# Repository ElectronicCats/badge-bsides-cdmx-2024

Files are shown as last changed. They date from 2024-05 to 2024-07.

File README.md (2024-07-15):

# Badge bsides CDMX 2024

## Getting started

1. Connect Badge via USB to your computer.
2. Open the serial port indicated for the badge on your computer through a program such as Arduino IDE, Putty or Screen at 115200 bauds.
3. The badge text should appear in the terminal.

## Tecnologia

- ESP32C6
- Neopixel LEDs
- USB C
- Display OLED
- 2x AA Battery Holder
- Shitty Addon Connector

## Gratitude
Do you want to say thank you? Tag these companies on social networks and show them your badge, thanks to them it is possible

- [HSBC](https://www.hsbc.com.mx/)
- [ElectronicCats](https://electroniccats.com/)
- [Bsides CDMX](https://bsidescdmx.org/)

## License

Electronic Cats invests time and resources providing this open source design, please support Electronic Cats and open-source hardware by purchasing products from Electronic Cats!

Designed by Electronic Cats.

Hardware released under an CERN Open Hardware Licence v1.2. See the LICENSE_HARDWARE file for more information.

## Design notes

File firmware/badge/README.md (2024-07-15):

# BSides badge developer guide

This document is intended to help developers get started with the BSides badge firmware. The badge is based on the ESP32 microcontroller and is programmed using the ESP-IDF framework.

## Getting started

1. Install the ESP-IDF framework by following the instructions at https://docs.espressif.com/projects/esp-idf/en/latest/get-started/index.html

2. Clone the BSides badge firmware repository:

Using HTTPS:
```
git clone https://github.com/ElectronicCats/badge-bsides-cdmx-2024.git
```

Using SSH:
```
git clone git@github.com:ElectronicCats/badge-bsides-cdmx-2024.git
```

3. Change to the firmware directory:
```
cd badge-bsides-cdmx-2024/firmware/badge
```

4. Connect your badge to your computer using a USB cable and check the port it is connected to.

> On Windows, you can check it in the Device Manager, on Linux you can check it with the `ls /dev/ttyUSB*` or `ls /dev/ttyACM*` command, and on macOS you can check it with the `ls /dev/cu.usb*` command.

6. Set the target to ESP32-C6:

```bash
idf.py set-target esp32c6
```

6. Build the firmware:

```bash
idf.py build
```

7. Flash the firmware:

```bash
idf.py -p $PORT flash
```

> Replace `$PORT` with the port your badge is connected to.

8. Monitor the output:

```bash
idf.py -p $PORT monitor
```

> You can do this steps at once by running `make all`.

## Using badge_connect_src library

The project uses the [badge_connect_bin](https://github.com/ElectronicCats/badge_connect_bin) library to interact with badges from different events. It is a pre-compiled version, so you can't modify it. If you need to debug, modify or add new features, you can use the source version.

To use the source version, follow these steps:

1. Clone the badge_connect_src repository (Not inside this repository, of course):

Using HTTPS:

```bash
git clone https://github.com/ElectronicCats/badge_connect_src.git
```

Using SSH:

```bash
git clone git@github.com:ElectronicCats/badge_connect_src.git
```

2. Get the path to the badge_connect_src directory:

```bash
cd badge_connect_src/
pwd
```

3. Set the path to an environment variable:

```bash
export BADGE_CONNECT_SRC_PATH=/path/to/badge_connect_src
```

That's it! Now you are using the source version. To verify it, go to `firmware/badge` in this project and run `idf.py menuconfig`. It should show you an interface where you can modify some options, if you see `Badge Connect  --->` you are using the source version.

To go back to the binary version, just unset the environment variable:

```bash
unset BADGE_CONNECT_SRC_PATH
```

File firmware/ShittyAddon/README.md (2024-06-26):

## Characteristics

* Microcontroller Puya PY32F002A    
  * PY32F002Ax5(20KB Flash/3KB RAM) SPI, USART, I2C, ADC.

## License
<a>
  
</a>

Designed by Electronic Cats for HackGDL

Electronic Cats invests time and resources in providing this open-source design. Please support Electronic Cats and open-source hardware by purchasing products from Electronic Cats!

Hardware released under ...

# PY32F0 SDK reference for Windows

[How to install the SDK for windows](https://github.com/ElectronicCats/puya-projects)

* Puya PY32F0 seriees template project for GNU Arm Embedded Toolchain
* Supported programmers: J-Link
* Supported IDE: VSCode

# File Structure

```
├── Build                       # Build results
├── Docs                        # Datesheets and User Manuals
├── Examples
│   ├── FreeRTOS                # FreeRTOS examples
│   ├── HAL                     # HAL library examples
│   └── LL                      # LL(Low Layer) library examples
├── Libraries
│   ├── BSP                     # SysTick delay and printf for debug
│   ├── BSP_LL                  # SysTick delay and printf for debug
│   ├── CMSIS
│   ├── FreeRTOS                # FreeRTOS library
│   ├── LDScripts               # LD files
│   ├── PY32F0xx_HAL_Driver     # MCU peripheral driver
│   └── PY32F0xx_LL_Driver      # MCU low layer peripheral driver
├── Makefile                    # Make config
├── Misc
│   ├── Flash
│   │   ├── JLinkDevices        # JLink flash loaders
│   │   └── Sources             # Flash algorithm source code
│   ├── Puya.PY32F0xx_DFP.x.pack # DFP pack file for PyOCD
│   └── SVD                     # SVD files
├── README.md
├── rules.mk                    # Pre-defined rules include in Makefile 
└── User                        # User application code
```

# Requirements

* Programmer
  * J-Link: J-Link OB programmer: https://linhkienthuduc.com/jlink-ob-072-mach-nap-cho-arm-cortex-m
* SEGGER J-Link Software and Documentation pack [https://www.segger.com/downloads/jlink/](https://www.segger.com/downloads/jlink/)
* GNU Arm Embedded Toolchain
* Make 

# Try Other Examples

[Forked Repository](https://github.com/IOsetting/py32f0-template)
More examples can be found in *Examples* folder of the forked repository, copy and replace the files under *User* folder of this repository to try different examples.

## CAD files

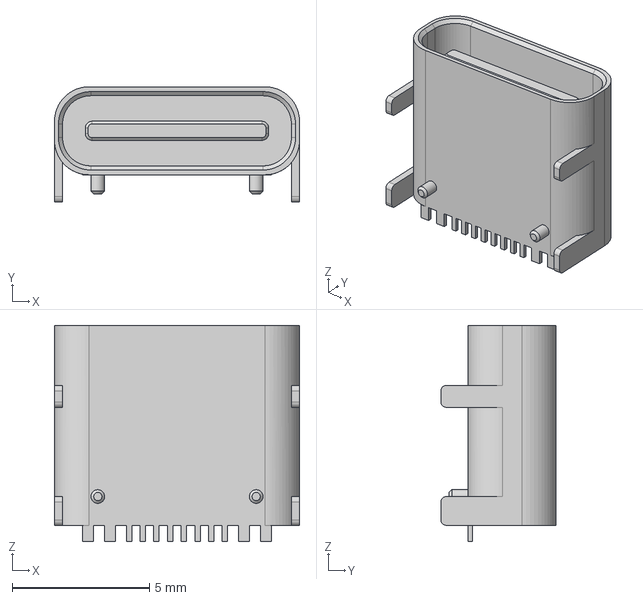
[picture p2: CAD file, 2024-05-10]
hardware/3d/HRO TYPE-C-31-M-12.step
8.94 x 4.21 x 7.90 mm

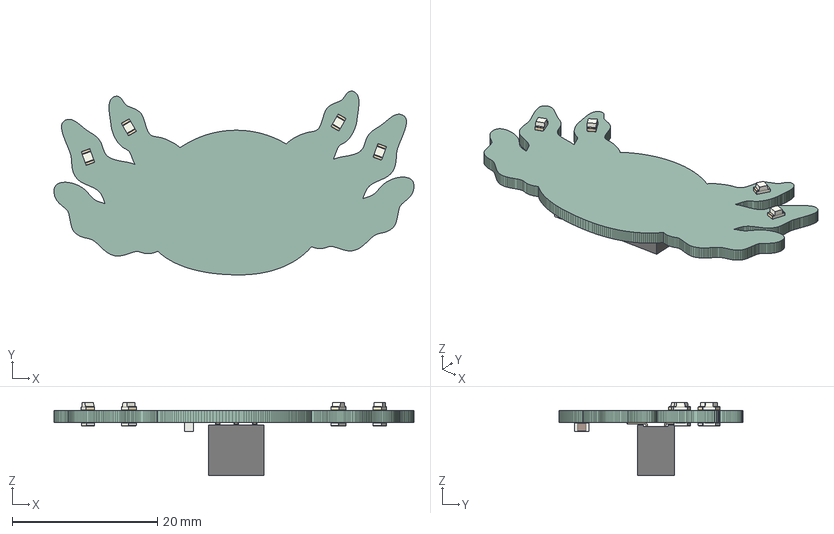
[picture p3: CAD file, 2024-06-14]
hardware/Bsides_2024_ShittyAddon/Bsides_2024_ShittyAddon.step
49.6 x 25.3 x 10.1 mm
LED_0805_2012Metric x 4
C_0805_2012Metric
PinSocket_2x03_P254mm_Vertical_SMD
R_0805_2012Metric x 4
Bsides_2024_ShittyAddon_PCB

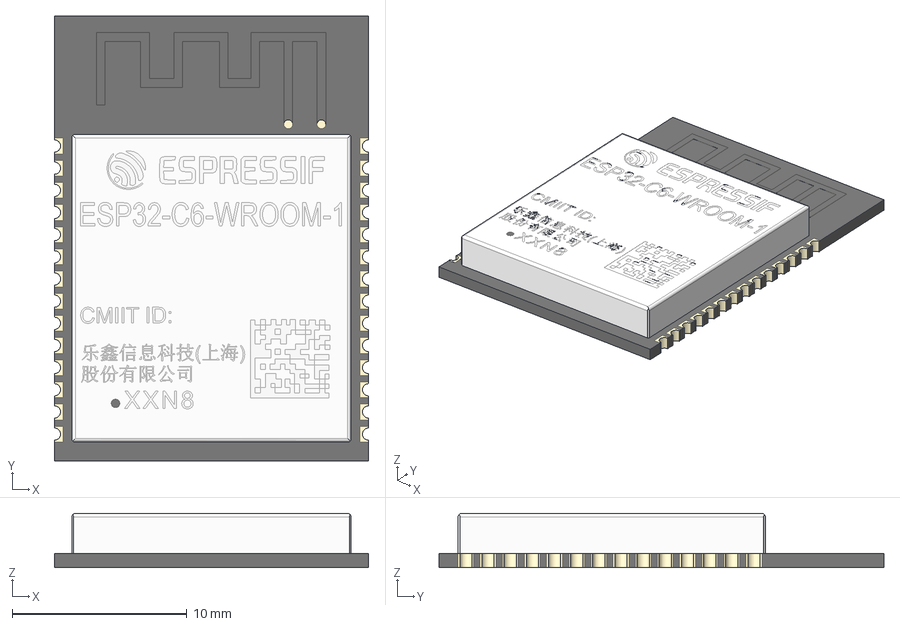
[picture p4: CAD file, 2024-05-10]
hardware/3d/ESP32-C6-WROOM-1-N4.step
18.0 x 25.5 x 3.11 mm

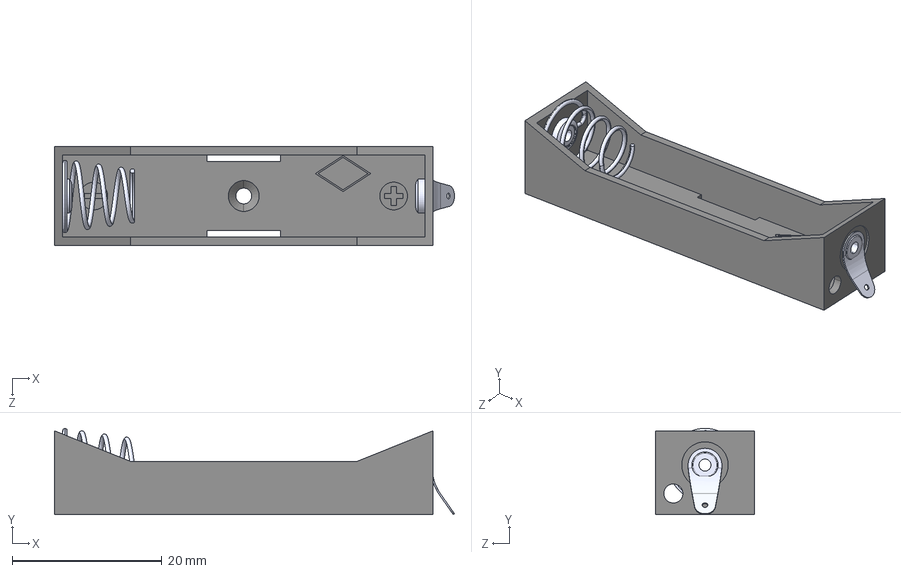
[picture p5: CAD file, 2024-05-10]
hardware/3d/BCAAAL.step
53.4 x 11.5 x 13.2 mm

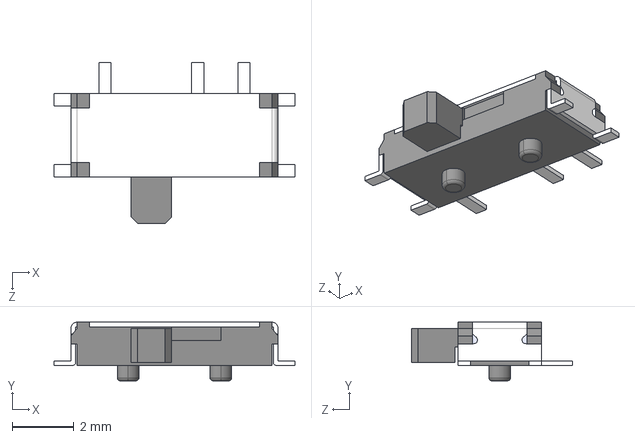
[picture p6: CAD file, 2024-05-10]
hardware/3d/MSK12C02.stp
7.80 x 1.90 x 5.20 mm

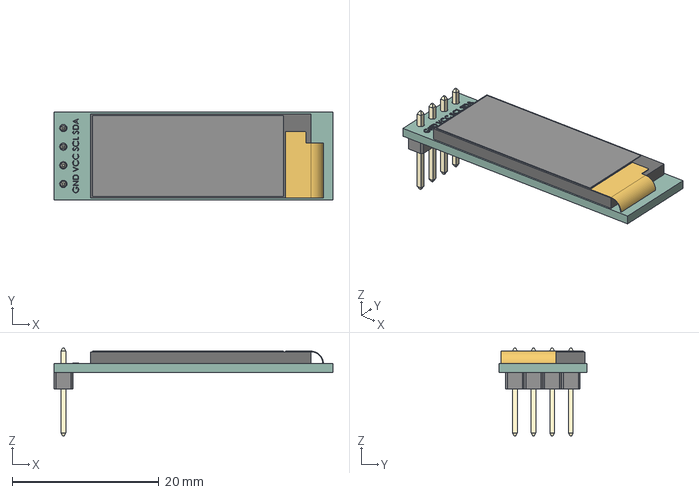
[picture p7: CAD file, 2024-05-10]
hardware/3d/128x32-OLED.STEP
38.0 x 12.0 x 11.9 mm

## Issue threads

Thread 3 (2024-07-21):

Bibliotecas Faltantes

ErikAlc-cyber, 2024-07-21:
Usando la extension de ESP-IDF apuntando a esp32c6, al intentar compilar el firmware para la badge obtengo un error de compilacion en el archivo CMAKE:

`Failed to resolve component 'esp_driver_uart'`

 El log muestra:

>  Parsed CXX implicit link information from above output:
  link line regex: [^( *|.*[/\])(riscv32-esp-elf-ld\.exe|CMAKE_LINK_STARTFILE-NOTFOUND|([^/\]+-)?ld|collect2)[^/\]*( |$)]
  ignore line: [Change Dir: C:/Users/eriks/Downloads/badge-bsides-cdmx-2024/firmware/badge/build/CMakeFiles/CMakeTmp]
  ignore line: []
  ignore line: [Run Build Command(s):C:/Users/eriks/.espressif/tools/ninja/1.11.1/ninja.exe cmTC_c5536 && [1/2] Building CXX object CMakeFiles/cmTC_c5536.dir/CMakeCXXCompilerABI.cpp.obj]
  ignore line: [Using built-in specs.]
  ignore line: [COLLECT_GCC=C:rf\.espressif\tools\riscv32-esp-elf\esp-13.2.0_20230928\riscv32-esp-elf\bin\riscv32-esp-elf-g++.exe]
  ignore line: [Target: riscv32-esp-elf]
  ignore line: [Configured with: /builds/idf/crosstool-NG/.build/HOST-x86_64-w64-mingw32/riscv32-esp-elf/src/gcc/configure --build=x86_64-build_pc-linux-gnu --host=x86_64-host_w64-mingw32 --target=riscv32-esp-elf --prefix=/builds/idf/crosstool-NG/builds/riscv32-esp-elf --exec_prefix=/builds/idf/crosstool-NG/builds/riscv32-esp-elf --with-local-prefix=/builds/idf/crosstool-NG/builds/riscv32-esp-elf/riscv32-esp-elf --with-headers=/builds/idf/crosstool-NG/builds/riscv32-esp-elf/riscv32-esp-elf/include --with-newlib --enable-threads=no --disable-shared --with-arch=rv32gc --with-abi=ilp32 --with-pkgversion='crosstool-NG esp-13.2.0_20230928' --disable-__cxa_atexit --enable-cxx-flags=-ffunction-sections --disable-libgomp --disable-libmudflap --disable-libmpx --disable-libssp --disable-libquadmath --disable-libquadmath-support --disable-libstdcxx-verbose --with-gmp=/builds/idf/crosstool-NG/.build/HOST-x86_64-w64-mingw32/riscv32-esp-elf/buildtools/complibs-host --with-mpfr=/builds/idf/crosstool-NG/.build/HOST-x86_64-w64-mingw32/riscv32-esp-elf/buildtools/complibs-host --with-mpc=/builds/idf/crosstool-NG/.build/HOST-x86_64-w64-mingw32/riscv32-esp-elf/buildtools/complibs-host --with-isl=/builds/idf/crosstool-NG/.build/HOST-x86_64-w64-mingw32/riscv32-esp-elf/buildtools/complibs-host --enable-lto --enable-target-optspace --without-long-double-128 --disable-nls --enable-multiarch --enable-languages=c,c++ --disable-libstdcxx-verbose --enable-threads=posix --enable-gcov-custom-rtio --enable-libstdcxx-time=yes --with-gnu-ld]
  ignore line: [Thread model: posix]
  ignore line: [Supported LTO compression algorithms: zlib]
  ignore line: [gcc version 13.2.0 (crosstool-NG esp-13.2.0_20230928) ]
  ignore line: [COLLECT_GCC_OPTIONS='-march=rv32imac_zicsr_zifencei' '-v' '-o' 'CMakeFiles/cmTC_c5536.dir/CMakeCXXCompilerABI.cpp.obj' '-c' '-mabi=ilp32' '-misa-spec=20191213' '-march=rv32imac_zicsr_zifencei' '-dumpdir' 'CMakeFiles/cmTC_c5536.dir/']
  ignore line: [ C:/Users/eriks/.espressif/tools/riscv32-esp-elf/esp-13.2.0_20230928/riscv32-esp-elf/bin/../libexec/gcc/riscv32-esp-elf/13.2.0/cc1plus.exe -quiet -v -imultilib rv32imac_zicsr_zifencei/ilp32 -iprefix C:/Users/eriks/.espressif/tools/riscv32-esp-elf/esp-13.2.0_20230928/riscv32-esp-elf/bin/../lib/gcc/riscv32-esp-elf/13.2.0/ C:/Users/eriks/.espressif/tools/cmake/3.24.0/share/cmake-3.24/Modules/CMakeCXXCompilerABI.cpp -quiet -dumpdir CMakeFiles/cmTC_c5536.dir/ -dumpbase CMakeCXXCompilerABI.cpp.cpp -dumpbase-ext .cpp -march=rv32imac_zicsr_zifencei -mabi=ilp32 -misa-spec=20191213 -march=rv32imac_zicsr_zifencei -version -o C:\AppData\Local\Temp\ccWxQuzr.s]
  ignore line: [GNU C++17 (crosstool-NG esp-13.2.0_20230928) version 13.2.0 (riscv32-esp-elf)]
  ignore line: [	compiled by GNU C version 6.3.0 20170516  GMP version 6.2.1  MPFR version 4.1.0  MPC version 1.2.1  isl version isl-0.24-GMP]
  ignore line: []
  ignore line: [GGC heuristics: --param ggc-min-expand=100 --param ggc-min-heapsize=131072]
  ignore line: [ignoring duplicate directory "C:/Users/eriks/.espressif/tools/riscv32-esp-elf/esp-13.2.0_20230928/riscv32-esp-elf/lib/gcc/../../lib/gcc/riscv32-esp-elf/13.2.0/../../../../riscv32-esp-elf/include/c++/13.2.0"]
  ignore line: [ignoring duplicate directory "C:/Users/eriks/.espressif/tools/riscv32-esp-elf/esp-13.2.0_20230928/riscv32-esp-elf/lib/gcc/../../lib/gcc/riscv32-esp-elf/13.2.0/../../../../riscv32-esp-elf/include/c++/13.2.0/riscv32-esp-elf/rv32imac_zicsr_zifencei/ilp32"]
  ignore line: [ignoring duplicate directory "C:/Users/eriks/.espressif/tools/riscv32-esp-elf/esp-13.2.0_20230928/riscv32-esp-elf/lib/gcc/../../lib/gcc/riscv32-esp-elf/13.2.0/../../../../riscv32-esp-elf/include/c++/13.2.0/backward"]
  ignore line: [ignoring duplicate directory "C:/Users/eriks/.espressif/tools/riscv32-esp-elf/esp-13.2.0_20230928/riscv32-esp-elf/lib/gcc/../../lib/gcc/riscv32-esp-elf/13.2.0/include"]
  ignore line: [ignoring duplicate directory "C:/Users/eriks/.espressif/tools/riscv32-esp-elf/esp-13.2.0_20230928/riscv32-esp-elf/lib/gcc/../../lib/gcc/riscv32-esp-elf/13.2.0/include-fixed"]
  ignore line: [ignoring duplicate directory "C:/Users/eriks/.espressif/tools/riscv32-esp-elf/esp-13.2.0_20230928/riscv32-esp-elf/lib/gcc/../../lib/gcc/riscv32-esp-elf/13.2.0/../../../../riscv32-esp-elf/sys-include"]
  ignore line: [ignoring duplicate directory "C:/Users/eriks/.espressif/tools/riscv32-esp-elf/esp-13.2.0_20230928/riscv32-esp-elf/lib/gcc/../../lib/gcc/riscv32-esp-elf/13.2.0/../../../../riscv32-esp-elf/include"]
  ignore line: [#include "..." search starts here:]
  ignore line: [#include <...> search starts here:]
  ignore line: [ C:/Users/eriks/.espressif/tools/riscv32-esp-elf/esp-13.2.0_20230928/riscv32-esp-elf/bin/../lib/gcc/riscv32-esp-elf/13.2.0/../../../../riscv32-esp-elf/include/c++/13.2.0]
  ignore line: [ C:/Users/eriks/.espressif/tools/riscv32-esp-elf/esp-13.2.0_20230928/riscv32-esp-elf/bin/../lib/gcc/riscv32-esp-elf/13.2.0/../../../../riscv32-esp-elf/include/c++/13.2.0/riscv32-esp-elf/rv32imac_zicsr_zifencei/ilp32]
  ignore line: [ C:/Users/eriks/.espressif/tools/riscv32-esp-elf/esp-13.2.0_20230928/riscv32-esp-elf/bin/../lib/gcc/riscv32-esp-elf/13.2.0/../../../../riscv32-esp-elf/include/c++/13.2.0/backward]
  ignore line: [ C:/Users/eriks/.espressif/tools/riscv32-esp-elf/esp-13.2.0_20230928/riscv32-esp-elf/bin/../lib/gcc/riscv32-esp-elf/13.2.0/include]
  ignore line: [ C:/Users/eriks/.espressif/tools/riscv32-esp-elf/esp-13.2.0_20230928/riscv32-esp-elf/bin/../lib/gcc/riscv32-esp-elf/13.2.0/include-fixed]
  ignore line: [ C:/Users/eriks/.espressif/tools/riscv32-esp-elf/esp-13.2.0_20230928/riscv32-esp-elf/bin/../lib/gcc/riscv32-esp-elf/13.2.0/../../../../riscv32-esp-elf/sys-include]
  ignore line: [ C:/Users/eriks/.espressif/tools/riscv32-esp-elf/esp-13.2.0_20230928/riscv32-esp-elf/bin/../lib/gcc/riscv32-esp-elf/13.2.0/../../../../riscv32-esp-elf/include]
  ignore line: [End of search list.]
  ignore line: [Compiler executable checksum: c3899898cbd00b593a05a0e9a2f92cb0]
  ignore line: [COLLECT_GCC_OPTIONS='-march=rv32imac_zicsr_zifencei' '-v' '-o' 'CMakeFiles/cmTC_c5536.dir/CMakeCXXCompilerABI.cpp.obj' '-c' '-mabi=ilp32' '-misa-spec=20191213' '-march=rv32imac_zicsr_zifencei' '-dumpdir' 'CMakeFiles/cmTC_c5536.dir/']
  ignore line: [ C:/.espressif/tools/riscv32-esp-elf/esp-13.2.0_20230928/riscv32-esp-elf/bin/../lib/gcc/riscv32-esp-elf/13.2.0/../../../../riscv32-esp-elf/bin/as.exe -v --traditional-format -march=rv32imac_zicsr_zifencei -march=rv32imac_zicsr_zifencei -mabi=ilp32 -misa-spec=20191213 -o CMakeFiles/cmTC_c5536.dir/CMakeCXXCompilerABI.cpp.obj C:\AppData\Local\Temp\ccWxQuzr.s]
  ignore line: [GNU assembler version 2.41 (riscv32-esp-elf) using BFD version (crosstool-NG esp-13.2.0_20230928) 2.41]
  ignore line: [COMPILER_PATH=C:/.espressif/tools/riscv32-esp-elf/esp-13.2.0_20230928/riscv32-esp-elf/bin/../libexec/gcc/riscv32-esp-elf/13.2.0/]
  ignore line: [C:/.espressif/tools/riscv32-esp-elf/esp-13.2.0_20230928/riscv32-esp-elf/bin/../libexec/gcc/]
  ignore line: [C:/.espressif/tools/riscv32-esp-elf/esp-13.2.0_20230928/riscv32-esp-elf/bin/../lib/gcc/riscv32-esp-elf/13.2.0/../../../../riscv32-esp-elf/bin/]
  ignore line: [LIBRARY_PATH=C:/.espressif/tools/riscv32-esp-elf/esp-13.2.0_20230928/riscv32-esp-elf/bin/../lib/gcc/riscv32-esp-elf/13.2.0/rv32imac_zicsr_zifencei/ilp32/]
  ignore line: [C:/.espressif/tools/riscv32-esp-elf/esp-13.2.0_20230928/riscv32-esp-elf/bin/../lib/gcc/riscv32-esp-elf/13.2.0/../../../../riscv32-esp-elf/lib/rv32imac_zicsr_zifencei/ilp32/]
  ignore line: [C:/.espressif/tools/riscv32-esp-elf/esp-13.2.0_20230928/riscv32-esp-elf/bin/../lib/gcc/riscv32-esp-elf/13.2.0/]
  ignore line: [C:/.espressif/tools/riscv32-esp-elf/esp-13.2.0_20230928/riscv32-esp-elf/bin/../lib/gcc/]
  ignore line: [C:/.espressif/tools/riscv32-esp-elf/esp-13.2.0_20230928/riscv32-esp-elf/bin/../lib/gcc/riscv32-esp-elf/13.2.0/../../../../riscv32-esp-elf/lib/]
  ignore line: [COLLECT_GCC_OPTIONS='-march=rv32imac_zicsr_zifencei' '-v' '-o' 'CMakeFiles/cmTC_c5536.dir/CMakeCXXCompilerABI.cpp.obj' '-c' '-mabi=ilp32' '-misa-spec=20191213' '-march=rv32imac_zicsr_zifencei' '-dumpdir' 'CMakeFiles/cmTC_c5536.dir/CMakeCXXCompilerABI.cpp.']
  ignore line: [[2/2] Linking CXX executable cmTC_c5536]
  ignore line: [Using built-in specs.]
  ignore line: [Reading specs from C:/.espressif/tools/riscv32-esp-elf/esp-13.2.0_20230928/riscv32-esp-elf/bin/../lib/gcc/riscv32-esp-elf/13.2.0/../../../../riscv32-esp-elf/lib/nosys.specs]
  ignore line: [rename spec link_gcc_c_sequence to nosys_link_gcc_c_sequence]
  ignore line: [COLLECT_GCC=C:\.espressif\tools\riscv32-esp-elf\esp-13.2.0_20230928\riscv32-esp-elf\bin\riscv32-esp-elf-g++.exe]
  ignore line: [COLLECT_LTO_WRAPPER=C:/.espressif/tools/riscv32-esp-elf/esp-13.2.0_20230928/riscv32-esp-elf/bin/../libexec/gcc/riscv32-esp-elf/13.2.0/lto-wrapper.exe]
  ignore line: [Target: riscv32-esp-elf]
  ignore line: [Configured with: /builds/idf/crosstool-NG/.build/HOST-x86_64-w64-mingw32/riscv32-esp-elf/src/gcc/configure --build=x86_64-build_pc-linux-gnu --host=x86_64-host_w64-mingw32 --target=riscv32-esp-elf --prefix=/builds/idf/crosstool-NG/builds/riscv32-esp-elf --exec_prefix=/builds/idf/crosstool-NG/builds/riscv32-esp-elf --with-local-prefix=/builds/idf/crosstool-NG/builds/riscv32-esp-elf/riscv32-esp-elf --with-headers=/builds/idf/crosstool-NG/builds/riscv32-esp-elf/riscv32-esp-elf/include --with-newlib --enable-threads=no --disable-shared --with-arch=rv32gc --with-abi=ilp32 --with-pkgversion='crosstool-NG esp-13.2.0_20230928' --disable-__cxa_atexit --enable-cxx-flags=-ffunction-sections --disable-libgomp --disable-libmudflap --disable-libmpx --disable-libssp --disable-libquadmath --disable-libquadmath-support --disable-libstdcxx-verbose --with-gmp=/builds/idf/crosstool-NG/.build/HOST-x86_64-w64-mingw32/riscv32-esp-elf/buildtools/complibs-host --with-mpfr=/builds/idf/crosstool-NG/.build/HOST-x86_64-w64-mingw32/riscv32-esp-elf/buildtools/complibs-host --with-mpc=/builds/idf/crosstool-NG/.build/HOST-x86_64-w64-mingw32/riscv32-esp-elf/buildtools/complibs-host --with-isl=/builds/idf/crosstool-NG/.build/HOST-x86_64-w64-mingw32/riscv32-esp-elf/buildtools/complibs-host --enable-lto --enable-target-optspace --without-long-double-128 --disable-nls --enable-multiarch --enable-languages=c,c++ --disable-libstdcxx-verbose --enable-threads=posix --enable-gcov-custom-rtio --enable-libstdcxx-time=yes --with-gnu-ld]
  ignore line: [Thread model: posix]
  ignore line: [Supported LTO compression algorithms: zlib]
  ignore line: [gcc version 13.2.0 (crosstool-NG esp-13.2.0_20230928) ]
  ignore line: [COMPILER_PATH=C:/.espressif/tools/riscv32-esp-elf/esp-13.2.0_20230928/riscv32-esp-elf/bin/../libexec/gcc/riscv32-esp-elf/13.2.0/]
  ignore line: [C:/.espressif/tools/riscv32-esp-elf/esp-13.2.0_20230928/riscv32-esp-elf/bin/../libexec/gcc/]
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
ErikAlc-cyber, 2024-07-22:
Ya encontre una solucion, se debe usar especificamente ESP-IDF v5.3.0 para que incluya las bibliotecas necesarias

Closed 2024-07-22.

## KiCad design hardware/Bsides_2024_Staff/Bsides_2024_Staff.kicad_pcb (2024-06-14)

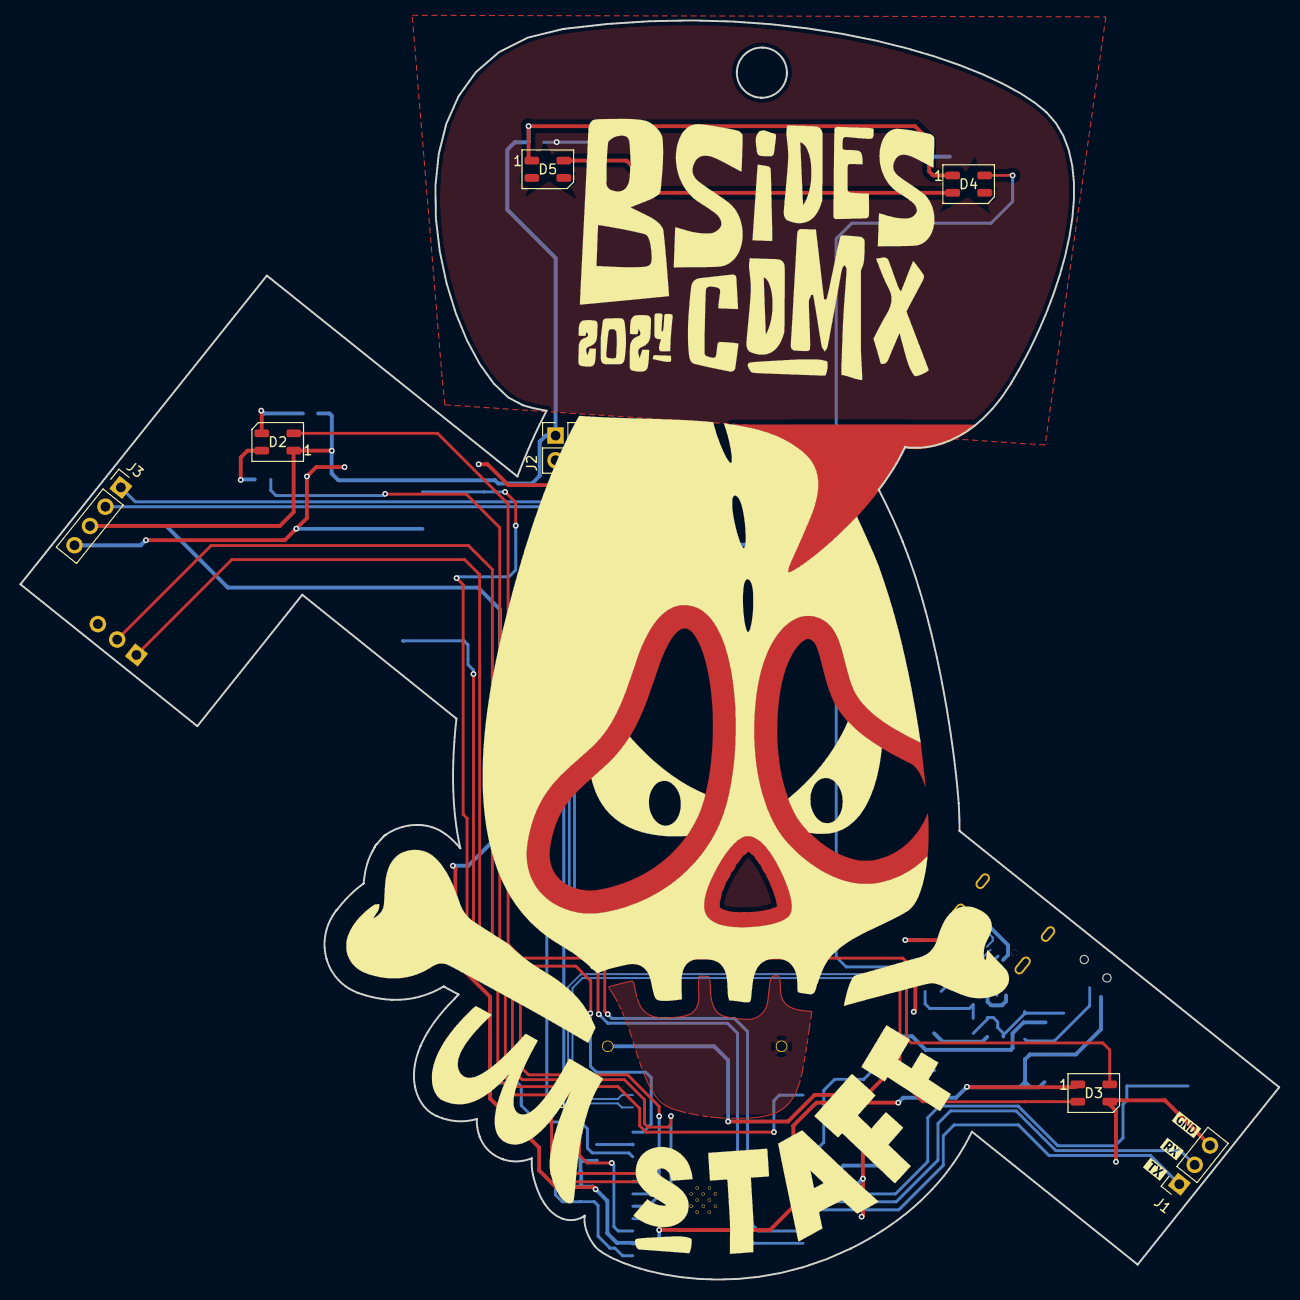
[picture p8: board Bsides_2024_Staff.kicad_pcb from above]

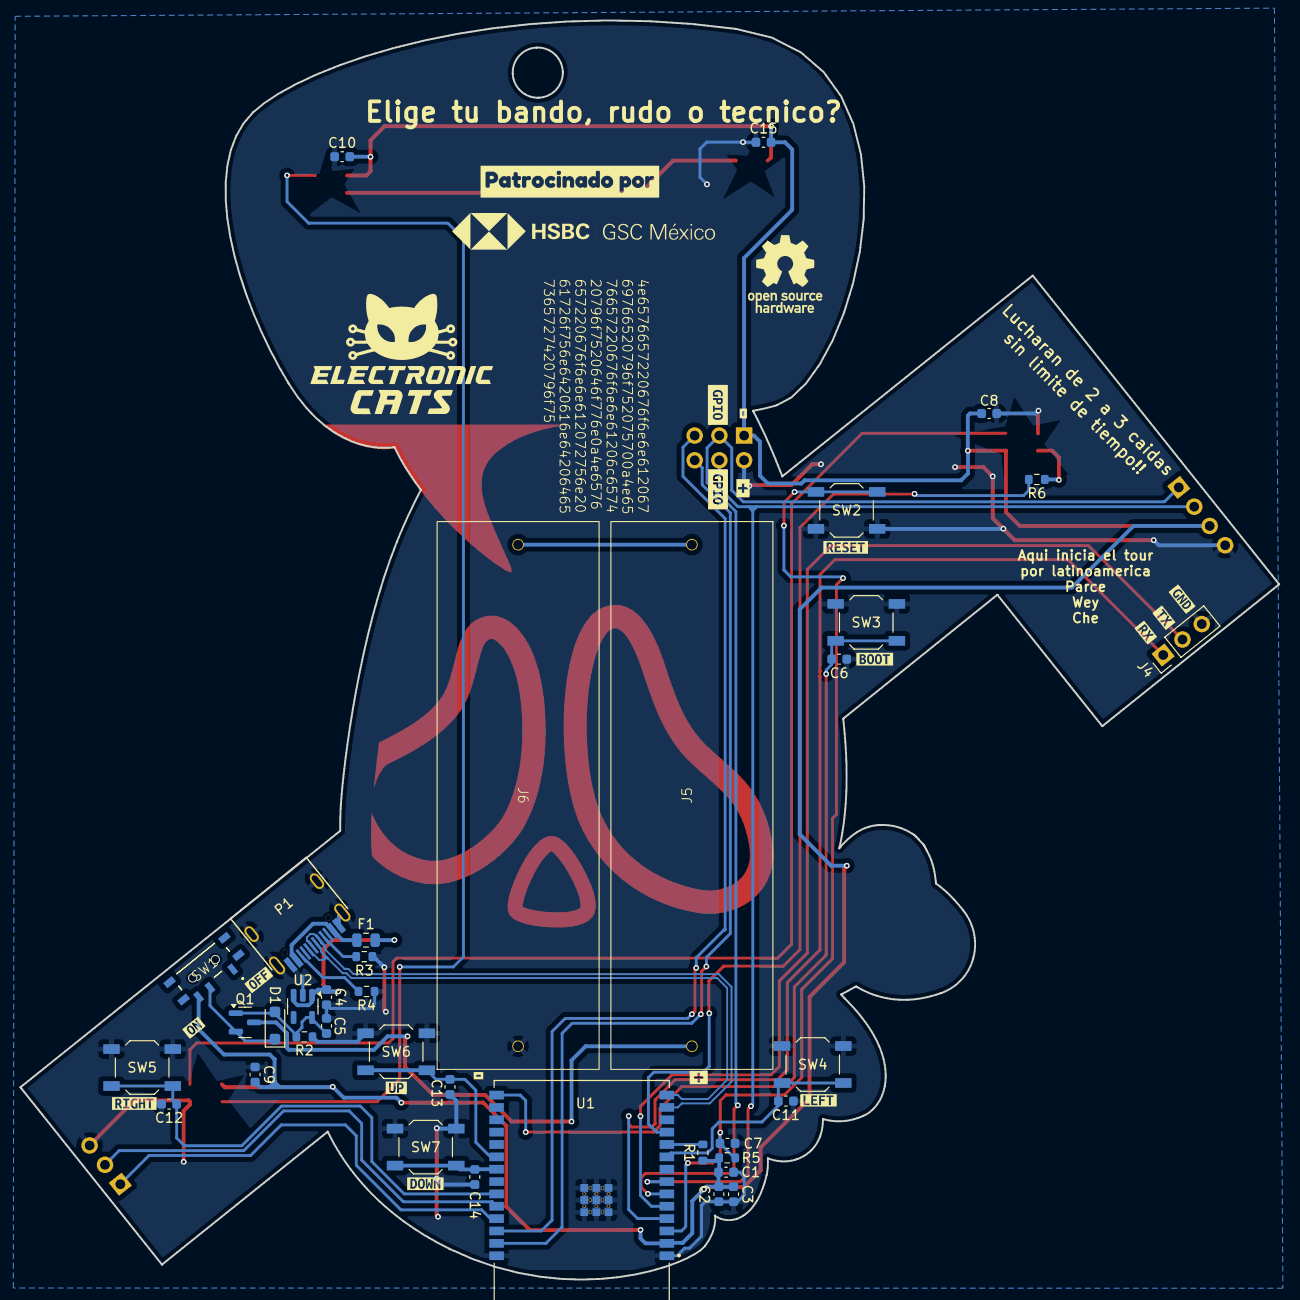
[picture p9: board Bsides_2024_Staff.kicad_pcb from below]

Board: 2 copper layers, 129.4 x 129.4 mm, 66 parts (55 on the bottom side), 32 nets.

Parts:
C1: 1uF; C_0603_1608Metric
C2, C3, C4, C5: 10uF; C_0603_1608Metric
C6, C7, C8, C9, C10, C11, C12, C13, C14, C15: 0.1uF; C_0603_1608Metric
D1: MBR120; D_SOD-123F
D2, D3, D4, D5: WS2812B; LED_WS2812B-Mini_PLCC4_3.5x3.5mm
F1: 0.75A; Fuse_0805_2012Metric
J1: Serial_IN; PinSocket_1x03_P2.54mm_Vertical
J2: Add_On; PinSocket_2x03_P2.54mm_Vertical
J3: OLED; Display OLED 128 x32
J4: Serial_OUT; PinHeader_1x03_P2.54mm_Vertical
J5, J6: Battery; BH-AA-A1AJ020
P1: USB_C_Plug_USB2.0; C393939
Q1: DMG3415U-7; SOT-23
R1: 3.3K; R_0603_1608Metric
R2: 100K; R_0603_1608Metric
R3, R4: 5k1; R_0603_1608Metric
R5: 10K; R_0603_1608Metric
R6: 470; R_0603_1608Metric
Ref**: Val**; Badge_Staff_Bsides_2024_CDMX
SW1: ON; MSK12C02
SW2, SW4, SW6: RESET; SW_SPST_TL3342
SW3: BOOT; SW_SPST_TL3342
SW5, SW7: SW_SPST_TL3342
U1: ESP32-C6-WROOM-1-N4; XCVR_ESP32-C6-WROOM-1-N8
U2: AP2112K-3.3; SOT-23-5
kibuzzard-666B5A62, kibuzzard-666B5A62#2: G***; kibuzzard-666B5A62
kibuzzard-666B5A91, kibuzzard-666B5A91#2: G***; kibuzzard-666B5A91
kibuzzard-666B5AA1, kibuzzard-666B5AA1#2: G***; kibuzzard-666B5AA1
kibuzzard-666B5BCA, kibuzzard-666B5BCA#2: G***; kibuzzard-666B5BCA
kibuzzard-666B5C0A, kibuzzard-666B5C0A#2: G***; kibuzzard-666B5C0A
kibuzzard-666C8E87: G***; kibuzzard-666C8E87
kibuzzard-666C76B6: G***; kibuzzard-666C76B6
kibuzzard-666C89E6: G***; kibuzzard-666C89E6
kibuzzard-666C89FF: G***; kibuzzard-666C89FF
kibuzzard-666C926F: G***; kibuzzard-666C926F
kibuzzard-666C7661: G***; kibuzzard-666C7661
kibuzzard-666C8913: G***; kibuzzard-666C8913
kibuzzard-666C8921: G***; kibuzzard-666C8921
kibuzzard-666C8949: G***; kibuzzard-666C8949
kibuzzard-666C8959: G***; kibuzzard-666C8959
kibuzzard-666C9266: G***; kibuzzard-666C9266

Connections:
+BATT: J5.2, Q1.3 (D)
/BOOT: C6.2, SW3.2, U1.15 (IO9)
/D+: P1.A6 (D+), U1.14 (IO13)
/D-: P1.A7 (D-), U1.13 (IO12)
/DOWN: C14.2, SW7.2, U1.21 (IO23)
/EN: C7.2, R5.1, SW2.2, U1.3 (EN)
/GPIO2: J2.6, U1.27 (IO2)
/GPIO3: J2.5, U1.26 (IO3)
/LEFT: C11.2, SW4.2, U1.9 (IO1)
/PIN: R6.1, U1.11 (IO10)
/RIGHT: C12.2, SW5.2, U1.23 (IO15)
/RX: J1.2, U1.24 (RXD0)
/RX1: J4.1, U1.4 (IO4)
/SCL: J2.4, J3.2, U1.7 (IO7)
/SDA: J2.3, J3.1, U1.6 (IO6)
/TX: J1.1, U1.25 (TXD0)
/TX1: J4.2, U1.5 (IO5)
/UP: C13.2, SW6.2, U1.20 (IO22)
/VOUT: C1.1, C2.1, C3.1, C8.2, C9.2, C10.2, C15.2, D2.1 (VDD), D3.1 (VDD), D4.1 (VDD), D5.1 (VDD), J2.1, J3.3, R1.2, R5.2, SW1.3 (A), U1.2 (3V3)
GND: C1.2, C2.2, C3.2, C4.2, C5.2, C6.1, C7.1, C8.1, C9.1, C10.1, C11.1, C12.1, C13.1, C14.1, C15.1, D2.3 (VSS), D3.3 (VSS), D4.3 (VSS), D5.3 (VSS), J1.3, J2.2, J3.4, J4.3, J6.1, P1.A1 (GND), P1.S1 (SHIELD), R2.2, R3.1, R4.1, SW2.1, SW3.1, SW4.1, SW5.1, SW6.1, SW7.1, U1.1 (GND), U1.28 (GND), U1.29 (GND), U1.30 (GND), U1.31 (GND), U1.32 (GND), U1.33 (GND), U1.34 (GND), U1.35 (GND), U1.36 (GND), U1.37 (GND), U2.2 (GND)
unnamed: C5.1, D1.2 (A), Q1.1 (G), R2.1, U2.5 (VOUT)
unnamed: D1.1 (K), Q1.2 (S), SW1.2 (B)
unnamed: D2.4 (DIN), R6.2
unnamed: D2.2 (DOUT), D3.4 (DIN)
unnamed: D3.2 (DOUT), D4.4 (DIN)
unnamed: D4.2 (DOUT), D5.4 (DIN)
unnamed: F1.1, P1.A4 (VBUS)
unnamed: J5.1, J6.2
unnamed: P1.A5 (CC), R3.2
unnamed: P1.B5 (VCONN), R4.2
unnamed: R1.1, U1.10 (IO8)
VBUS: C4.1, F1.2, U2.1 (VIN), U2.3 (EN)

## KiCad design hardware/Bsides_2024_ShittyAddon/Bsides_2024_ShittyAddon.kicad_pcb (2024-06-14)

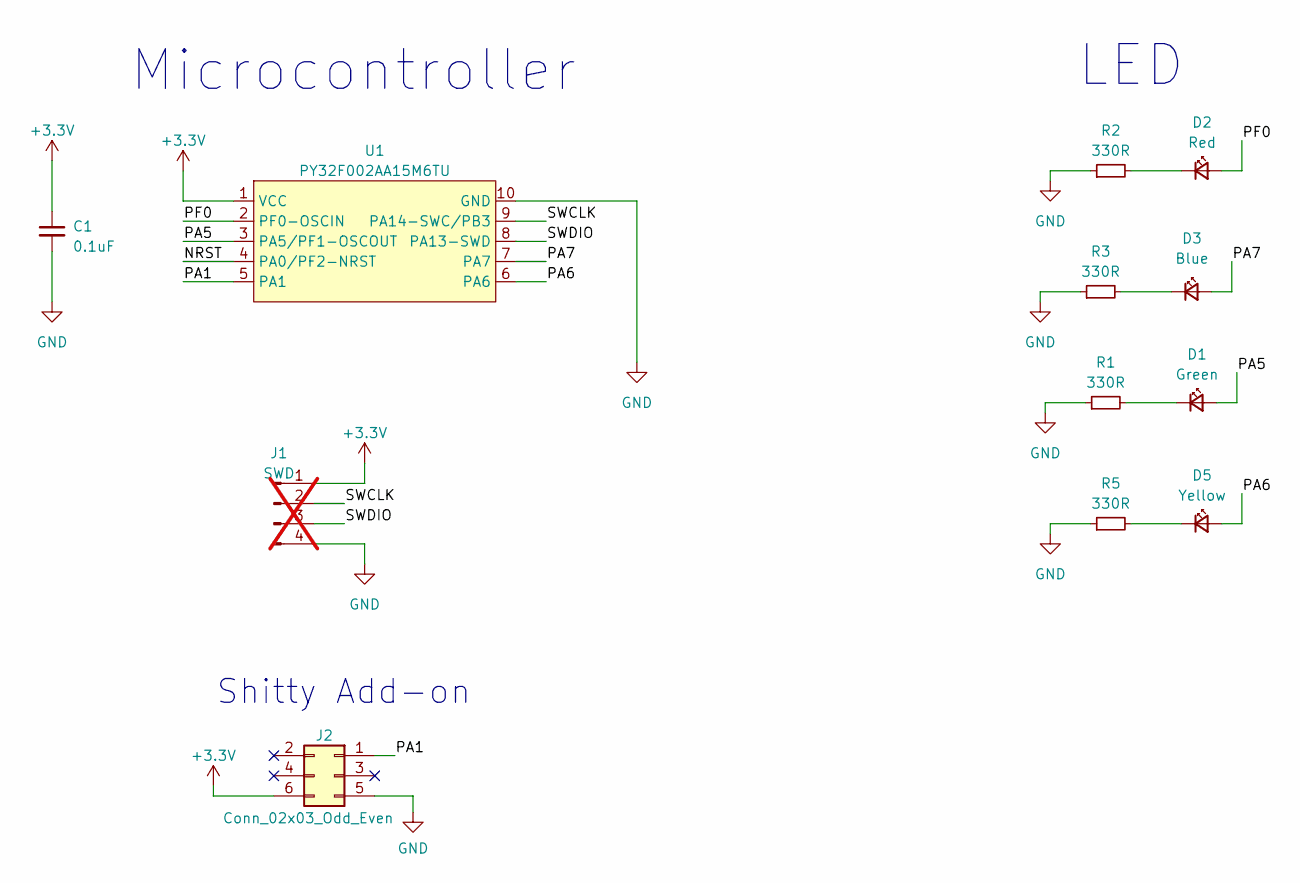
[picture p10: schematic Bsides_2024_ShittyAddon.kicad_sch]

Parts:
C1: 0.1uF; C_0805_2012Metric; LCSC# C282732
D1: Green; LED_0805_2012Metric; LCSC# C965815
D2: Red; LED_0805_2012Metric; LCSC# C965812
D3: Blue; LED_0805_2012Metric; LCSC# C205441
D5: Yellow; LED_0805_2012Metric; LCSC# C84261
J1: SWD; PinHeader_1x04_P2.54mm_Vertical; not fitted
J2: Conn_02x03_Odd_Even; B-2100N06P-B111_CKM; LCSC# C124390
R1, R2, R3, R5: 330R; R_0805_2012Metric; LCSC# C2907321
U1: PY32F002AA15M6TU; PY32F002AA15M; LCSC# C5292058

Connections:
+3.3V: C1.1, J1.1, J2.6, U1.1 (VCC)
/NRST: U1.4 (PA0/PF2-NRST)
/PA1: J2.1, U1.5 (PA1)
/PA5: D1.2 (A), U1.3 (PA5/PF1-OSCOUT)
/PA6: D5.2 (A), U1.6 (PA6)
/PA7: D3.2 (A), U1.7 (PA7)
/PF0: D2.2 (A), U1.2 (PF0-OSCIN)
/SWCLK: J1.2, U1.9 (PA14-SWC/PB3)
/SWDIO: J1.3, U1.8 (PA13-SWD)
GND: C1.2, J1.4, J2.5, R1.1, R2.1, R3.1, R5.1, U1.10 (GND)
unnamed: D1.1 (K), R1.2
unnamed: D2.1 (K), R2.2
unnamed: D3.1 (K), R3.2
unnamed: D5.1 (K), R5.2

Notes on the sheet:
Microcontroller
Shitty Add-on
LED

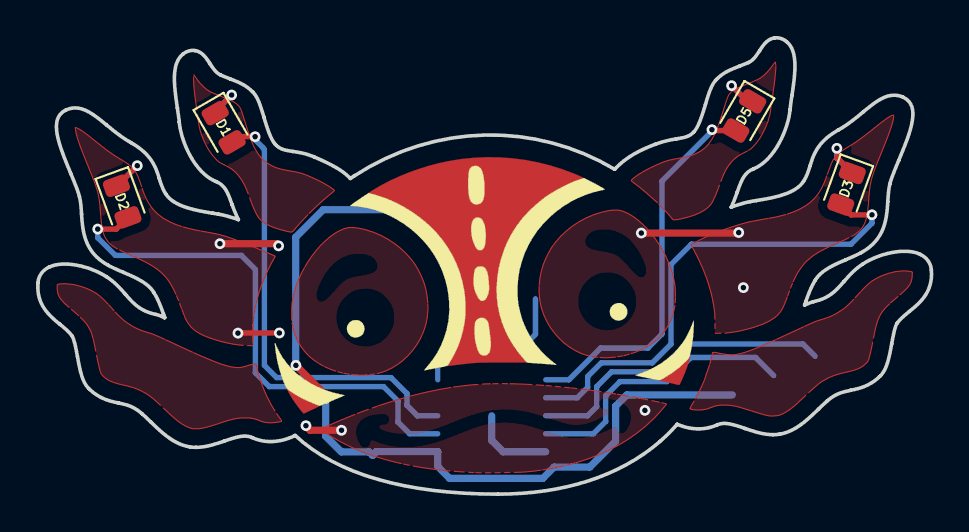
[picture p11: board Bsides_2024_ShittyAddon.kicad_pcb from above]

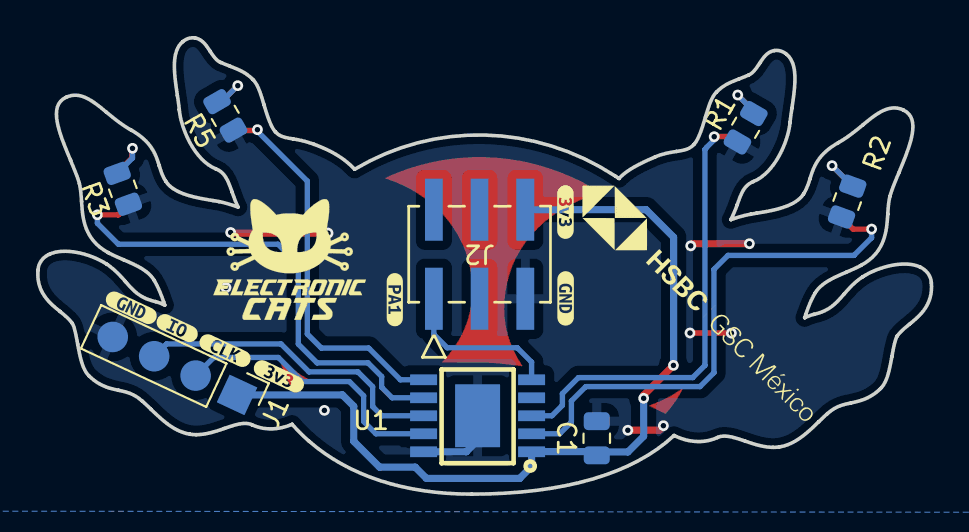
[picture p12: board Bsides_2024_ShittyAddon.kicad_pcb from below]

Board: 2 copper layers, 49.7 x 25.4 mm, 20 parts (15 on the bottom side), 13 nets.

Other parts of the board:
Ref**: Val**; Ajolote-bsidescdmx_A
kibuzzard-666C77E0, kibuzzard-666C77E0#2: G***; kibuzzard-666C77E0
kibuzzard-666C787C: G***; kibuzzard-666C787C
kibuzzard-666C7809, kibuzzard-666C7809#2: G***; kibuzzard-666C7809
kibuzzard-666C7823: G***; kibuzzard-666C7823
kibuzzard-666C7874: G***; kibuzzard-666C7874

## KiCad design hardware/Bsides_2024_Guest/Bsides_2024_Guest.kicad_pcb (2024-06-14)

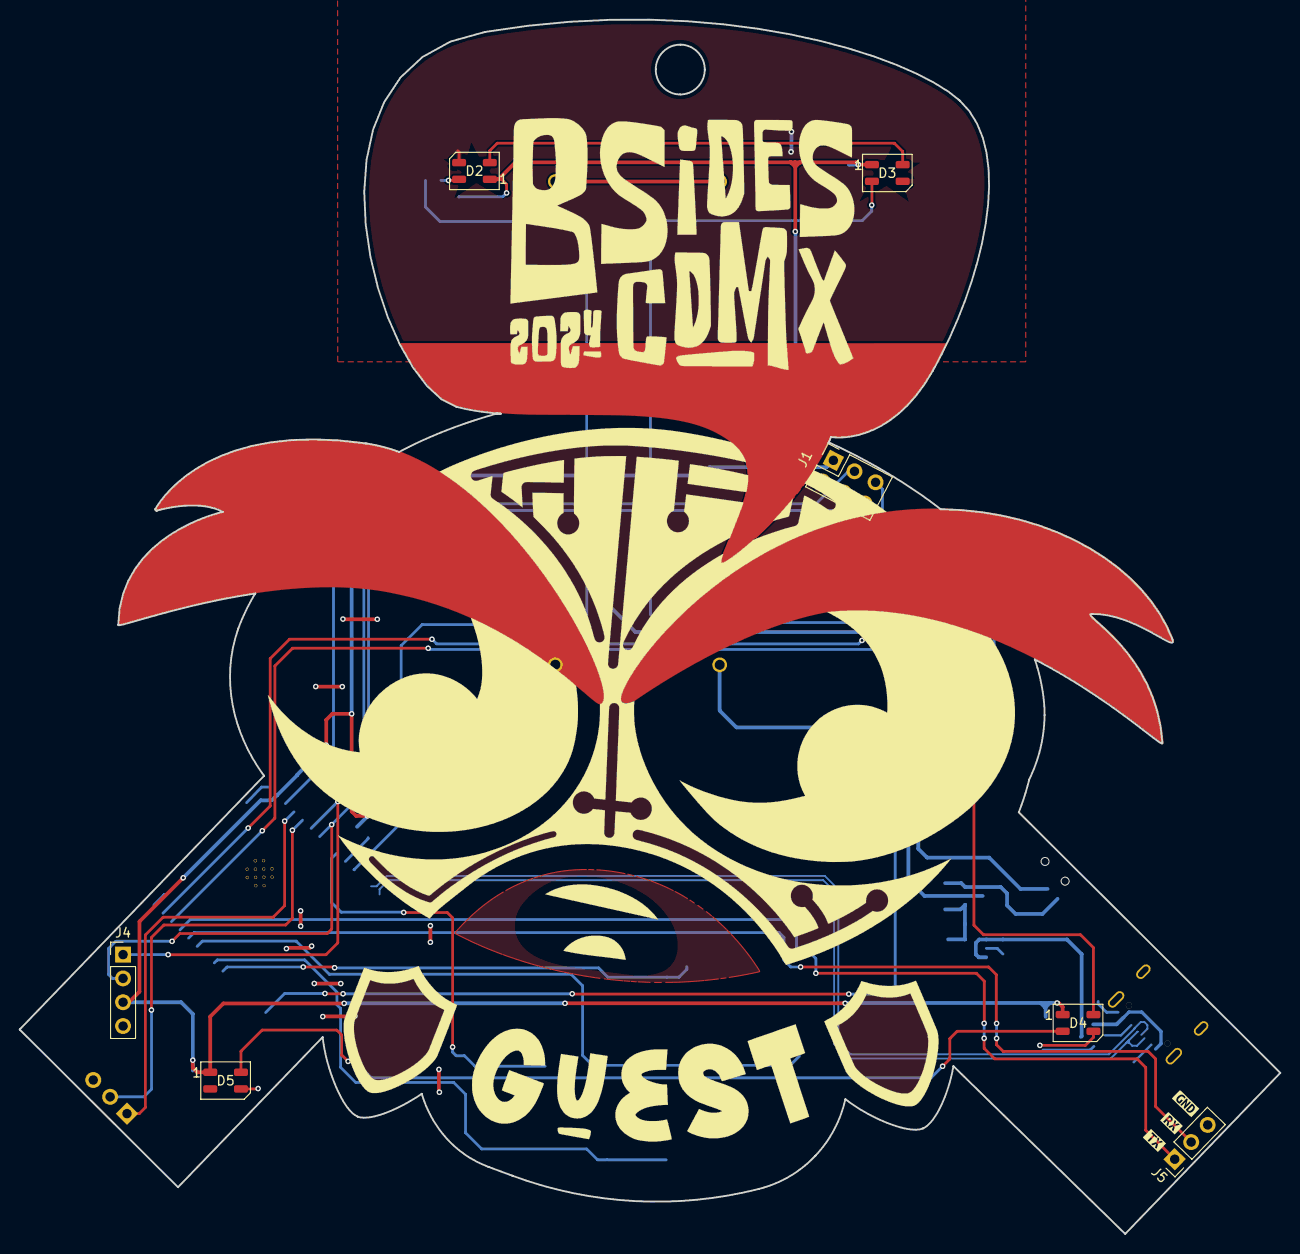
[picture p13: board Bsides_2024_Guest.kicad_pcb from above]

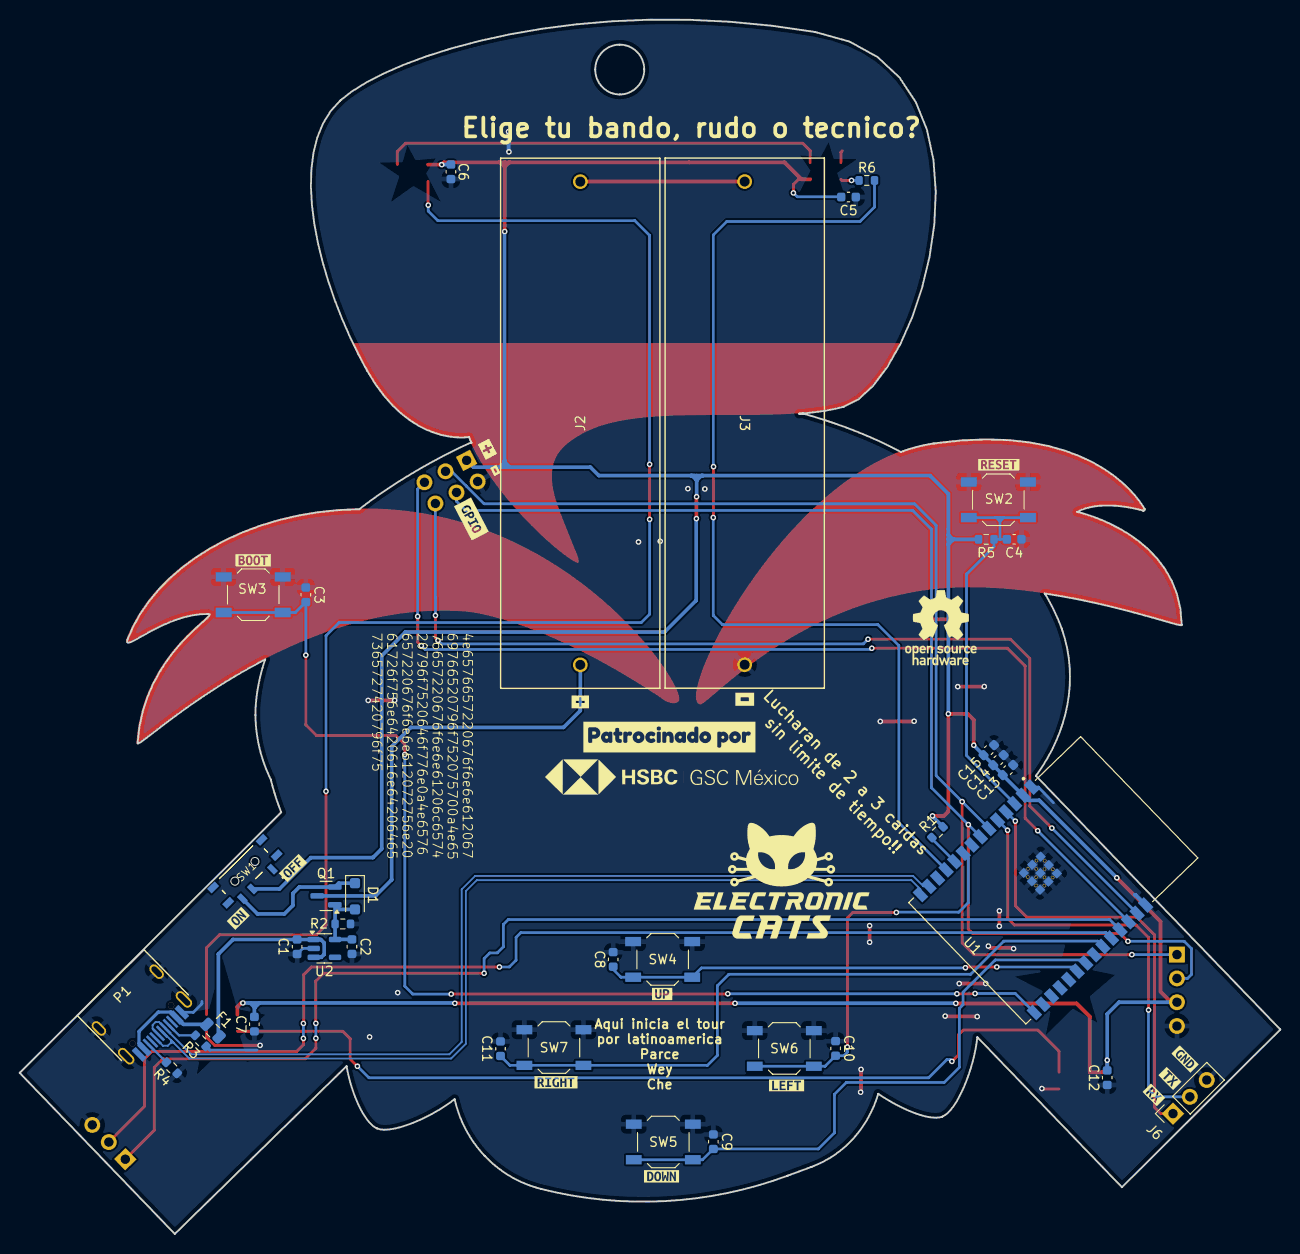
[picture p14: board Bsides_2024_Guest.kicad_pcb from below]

Board: 2 copper layers, 134.5 x 129.5 mm, 65 parts (54 on the bottom side), 32 nets.

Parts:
C1, C2, C14, C15: 10uF; C_0603_1608Metric
C3, C4, C5, C6, C7, C8, C9, C10, C11, C12: 0.1uF; C_0603_1608Metric
C13: 1uF; C_0603_1608Metric
D1: MBR120; D_SOD-123F
D2, D3, D4, D5: WS2812B; LED_WS2812B-Mini_PLCC4_3.5x3.5mm
F1: 0.75A; Fuse_0805_2012Metric
J1: Add_On; PinSocket_2x03_P2.54mm_Vertical
J2, J3: Battery; BATT_8BH-AA-A1AJ020_MYG
J4: OLED; Display OLED 128 x32
J5: Serial_IN; PinHeader_1x03_P2.54mm_Vertical
J6: Serial_OUT; PinSocket_1x03_P2.54mm_Vertical
P1: USB_C_Plug_USB2.0; C393939
Q1: DMG3415U-7; SOT-23
R1: 3.3K; R_0603_1608Metric
R2: 100K; R_0603_1608Metric
R3, R4: 5k1; R_0603_1608Metric
R5: 10K; R_0603_1608Metric
R6: 470; R_0603_1608Metric
Ref**: Val**; Badge_Guest_Bsides_2024_CDMX (1)
SW1: ON; MSK12C02
SW2, SW3, SW4, SW5, SW6, SW7: SW_SPST_TL3342
U1: ESP32-C6-WROOM-1U-N4; XCVR_ESP32-C6-WROOM-1-N8
U2: AP2112K-3.3; SOT-23-5
kibuzzard-666B5A62, kibuzzard-666B5A62#2: G***; kibuzzard-666B5A62
kibuzzard-666B5A91, kibuzzard-666B5A91#2: G***; kibuzzard-666B5A91
kibuzzard-666B5AA1, kibuzzard-666B5AA1#2: G***; kibuzzard-666B5AA1
kibuzzard-666B5BCA, kibuzzard-666B5BCA#2: G***; kibuzzard-666B5BCA
kibuzzard-666B5C0A: G***; kibuzzard-666B5C0A
kibuzzard-666B5E3B: G***; kibuzzard-666B5E3B
kibuzzard-666B5E08: G***; kibuzzard-666B5E08
kibuzzard-666B5E64: G***; kibuzzard-666B5E64
kibuzzard-666B5E88: G***; kibuzzard-666B5E88
kibuzzard-666B5E96: G***; kibuzzard-666B5E96
kibuzzard-666B5EA2: G***; kibuzzard-666B5EA2
kibuzzard-666B5ECE: G***; kibuzzard-666B5ECE
kibuzzard-666C8E87: G***; kibuzzard-666C8E87
kibuzzard-666C94C8: G***; kibuzzard-666C94C8
kibuzzard-666C662F: G***; kibuzzard-666C662F
kibuzzard-666C947A: G***; kibuzzard-666C947A

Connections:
+BATT: J2.2, Q1.3 (D)
/BOOT: C3.2, SW3.2, U1.15 (IO9)
/D+: P1.A6 (D+), U1.14 (IO13)
/D-: P1.A7 (D-), U1.13 (IO12)
/DOWN: C9.2, SW5.2, U1.21 (IO23)
/EN: C4.2, R5.1, SW2.2, U1.3 (EN)
/GPIO2: J1.6, U1.27 (IO2)
/GPIO3: J1.5, U1.26 (IO3)
/LEFT: C10.2, SW6.2, U1.9 (IO1)
/PIN: R6.1, U1.11 (IO10)
/RIGHT: C11.2, SW7.2, U1.23 (IO15)
/RX: J5.2, U1.24 (RXD0)
/RX1: J6.1, U1.4 (IO4)
/SCL: J1.4, J4.2, U1.7 (IO7)
/SDA: J1.3, J4.1, U1.6 (IO6)
/TX: J5.1, U1.25 (TXD0)
/TX1: J6.2, U1.5 (IO5)
/UP: C8.2, SW4.2, U1.20 (IO22)
/VOUT: C5.2, C6.2, C7.2, C12.2, C13.1, C14.1, C15.1, D2.1 (VDD), D3.1 (VDD), D4.1 (VDD), D5.1 (VDD), J1.1, J4.3, R1.2, R5.2, SW1.2 (B), U1.2 (3V3)
GND: C1.2, C2.2, C3.1, C4.1, C5.1, C6.1, C7.1, C8.1, C9.1, C10.1, C11.1, C12.1, C13.2, C14.2, C15.2, D2.3 (VSS), D3.3 (VSS), D4.3 (VSS), D5.3 (VSS), J1.2, J3.1, J4.4, J5.3, J6.3, P1.A1 (GND), P1.S1 (SHIELD), R2.2, R3.1, R4.1, SW2.1, SW3.1, SW4.1, SW5.1, SW6.1, SW7.1, U1.1 (GND), U1.28 (GND), U1.29 (GND), U1.30 (GND), U1.31 (GND), U1.32 (GND), U1.33 (GND), U1.34 (GND), U1.35 (GND), U1.36 (GND), U1.37 (GND), U2.2 (GND)
unnamed: C2.1, D1.2 (A), Q1.1 (G), R2.1, U2.5 (VOUT)
unnamed: D1.1 (K), Q1.2 (S), SW1.3 (A)
unnamed: D2.4 (DIN), R6.2
unnamed: D2.2 (DOUT), D3.4 (DIN)
unnamed: D3.2 (DOUT), D4.4 (DIN)
unnamed: D4.2 (DOUT), D5.4 (DIN)
unnamed: F1.1, P1.A4 (VBUS)
unnamed: J2.1, J3.2
unnamed: P1.A5 (CC), R3.2
unnamed: P1.B5 (VCONN), R4.2
unnamed: R1.1, U1.10 (IO8)
VBUS: C1.1, F1.2, U2.1 (VIN), U2.3 (EN)

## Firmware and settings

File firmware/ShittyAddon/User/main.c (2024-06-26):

/**
 ******************************************************************************
 * @file    main.c
 * @author  MCU Application Team
 * @brief   Main program body
 ******************************************************************************
 * @attention
 *
 * <h2><center>&copy; Copyright (c) Puya Semiconductor Co.
 * All rights reserved.</center></h2>
 *
 * <h2><center>&copy; Copyright (c) 2016 STMicroelectronics.
 * All rights reserved.</center></h2>
 *
 * This software component is licensed by ST under BSD 3-Clause license,
 * the "License"; You may not use this file except in compliance with the
 * License. You may obtain a copy of the License at:
 *                        opensource.org/licenses/BSD-3-Clause
 *
 * J-Link Connections: https://private-user-images.githubusercontent.com/44976441/277049150-2c44cddc-163c-4924-840f-2b99760bbca3.png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
 * PUYA instructions: https://github.com/ElectronicCats/puya-projects
 *
 ******************************************************************************
 */

/* Includes ------------------------------------------------------------------*/
#include "py32f0xx_bsp_printf.h"
#include <stdint.h>

/* Private define ------------------------------------------------------------*/
/* Private variables ---------------------------------------------------------*/
/* Private user code ---------------------------------------------------------*/
/* Private macro -------------------------------------------------------------*/
/* Private function prototypes -----------------------------------------------*/
static void APP_LedConfig(void);
uint16_t delay1 = 2000, delay3 = 3000;
uint8_t delay = 200, delay2 = 250, delay4 = 50, delay5 = 500;


// Unlock Sequence
void unlockSequence()
{
  //1
  HAL_GPIO_OnPin(GPIOA, GPIO_PIN_1);
  HAL_Delay(delay5);
  HAL_GPIO_OffPin(GPIOA, GPIO_PIN_1);
  HAL_Delay(delay5);
  //2
  HAL_GPIO_OnPin(GPIOA, GPIO_PIN_1);
  HAL_Delay(delay5);
  HAL_GPIO_OffPin(GPIOA, GPIO_PIN_1);
  HAL_Delay(delay5);
  //3
  HAL_GPIO_OnPin(GPIOA, GPIO_PIN_1);
  HAL_Delay(delay5);
  HAL_GPIO_OffPin(GPIOA, GPIO_PIN_1);
  HAL_Delay(delay5);
  //4
  HAL_GPIO_OnPin(GPIOA, GPIO_PIN_1);
  HAL_Delay(delay5);
  HAL_GPIO_OffPin(GPIOA, GPIO_PIN_1);
  HAL_Delay(delay5);
  //5
  HAL_GPIO_OnPin(GPIOA, GPIO_PIN_1);
  HAL_Delay(delay5);
  HAL_GPIO_OffPin(GPIOA, GPIO_PIN_1);
  HAL_Delay(delay5);
  //6
  HAL_GPIO_OnPin(GPIOA, GPIO_PIN_1);
  HAL_Delay(delay5);
  HAL_GPIO_OffPin(GPIOA, GPIO_PIN_1);
  HAL_Delay(delay5);
  //7
  HAL_GPIO_OnPin(GPIOA, GPIO_PIN_1);
  HAL_Delay(delay5);
  HAL_GPIO_OffPin(GPIOA, GPIO_PIN_1);
  HAL_Delay(delay5);
  //8
  HAL_GPIO_OnPin(GPIOA, GPIO_PIN_1);
  HAL_Delay(delay5);
  HAL_GPIO_OffPin(GPIOA, GPIO_PIN_1);
  HAL_Delay(delay5);
  //9
  HAL_GPIO_OnPin(GPIOA, GPIO_PIN_1);
  HAL_Delay(delay5);
  HAL_GPIO_OffPin(GPIOA, GPIO_PIN_1);
  HAL_Delay(delay5);
  //10
  HAL_GPIO_OnPin(GPIOA, GPIO_PIN_1);
  HAL_Delay(delay5);
  HAL_GPIO_OffPin(GPIOA, GPIO_PIN_1);
  HAL_Delay(delay5);
  //11
  HAL_GPIO_OnPin(GPIOA, GPIO_PIN_1);
  HAL_Delay(delay5);
  HAL_GPIO_OffPin(GPIOA, GPIO_PIN_1);
  HAL_Delay(delay5);
  //12
  HAL_GPIO_OnPin(GPIOA, GPIO_PIN_1);
  HAL_Delay(delay5);
  HAL_GPIO_OffPin(GPIOA, GPIO_PIN_1);
  HAL_Delay(delay5);
  //13
  HAL_GPIO_OnPin(GPIOA, GPIO_PIN_1);
  HAL_Delay(delay5);
  HAL_GPIO_OffPin(GPIOA, GPIO_PIN_1);
  HAL_Delay(delay5);
  //14
  HAL_GPIO_OnPin(GPIOA, GPIO_PIN_1);
  HAL_Delay(delay5);
  HAL_GPIO_OffPin(GPIOA, GPIO_PIN_1);
  HAL_Delay(delay5);
  //15
  HAL_GPIO_OnPin(GPIOA, GPIO_PIN_1);
  HAL_Delay(delay5);
  HAL_GPIO_OffPin(GPIOA, GPIO_PIN_1);
  HAL_Delay(delay5);
}

//On
void allonSequence()
{
  HAL_GPIO_OnPin(GPIOA, GPIO_PIN_5); 
  HAL_GPIO_OnPin(GPIOF, GPIO_PIN_0);
  HAL_GPIO_OnPin(GPIOA, GPIO_PIN_7); 
  HAL_GPIO_OnPin(GPIOA, GPIO_PIN_6); 
}

//Off
void alloffSequence()
{
  HAL_GPIO_OffPin(GPIOA, GPIO_PIN_6); 
  HAL_GPIO_OffPin(GPIOA, GPIO_PIN_5);
  HAL_GPIO_OffPin(GPIOF, GPIO_PIN_0); 
  HAL_GPIO_OffPin(GPIOA, GPIO_PIN_7);
}

// Sequence 1
void earsSequence()
{
  HAL_GPIO_OnPin(GPIOF, GPIO_PIN_0); 
  HAL_GPIO_OnPin(GPIOA, GPIO_PIN_5); 
  HAL_Delay(delay2);
  HAL_GPIO_OnPin(GPIOA, GPIO_PIN_7);
  HAL_GPIO_OnPin(GPIOA, GPIO_PIN_6);
  HAL_Delay(delay1);
  HAL_GPIO_OffPin(GPIOF, GPIO_PIN_0);
  HAL_GPIO_OffPin(GPIOA, GPIO_PIN_5);
  HAL_GPIO_OffPin(GPIOA, GPIO_PIN_7);
  HAL_GPIO_OffPin(GPIOA, GPIO_PIN_6);
  HAL_Delay(delay);

  HAL_GPIO_OnPin(GPIOA, GPIO_PIN_7);
  HAL_GPIO_OnPin(GPIOA, GPIO_PIN_6);
  HAL_GPIO_OnPin(GPIOF, GPIO_PIN_0); 
  HAL_GPIO_OnPin(GPIOA, GPIO_PIN_5);
  HAL_Delay(delay);
  HAL_GPIO_OffPin(GPIOF, GPIO_PIN_0);
  HAL_GPIO_OffPin(GPIOA, GPIO_PIN_5);
  HAL_GPIO_OffPin(GPIOA, GPIO_PIN_7);
  HAL_GPIO_OffPin(GPIOA, GPIO_PIN_6);
  HAL_Delay(delay);
}

// Sequence 2
void rouletteSequence()
{
  HAL_GPIO_OnPin(GPIOF, GPIO_PIN_0); 
  HAL_Delay(delay2);
  HAL_GPIO_OnPin(GPIOA, GPIO_PIN_5); 
  HAL_Delay(delay2);
  HAL_GPIO_OnPin(GPIOA, GPIO_PIN_6); 
  HAL_Delay(delay2);
  HAL_GPIO_OnPin(GPIOA, GPIO_PIN_7); 
  HAL_Delay(delay2);

  HAL_GPIO_OffPin(GPIOF, GPIO_PIN_0);
  HAL_Delay(delay2);
  HAL_GPIO_OffPin(GPIOA, GPIO_PIN_5);
  HAL_Delay(delay2);
  HAL_GPIO_OffPin(GPIOA, GPIO_PIN_6);
  HAL_Delay(delay2);
  HAL_GPIO_OffPin(GPIOA, GPIO_PIN_7);
  HAL_Delay(delay2);
}

// Sequence 3
void allSequence()
{ 
  HAL_GPIO_OnPin(GPIOA, GPIO_PIN_5); 
  HAL_GPIO_OnPin(GPIOF, GPIO_PIN_0);
  HAL_GPIO_OnPin(GPIOA, GPIO_PIN_7); 
  HAL_GPIO_OnPin(GPIOA, GPIO_PIN_6); 
  HAL_Delay(delay3);
  HAL_GPIO_OffPin(GPIOA, GPIO_PIN_5); 
  HAL_GPIO_OffPin(GPIOF, GPIO_PIN_0);
  HAL_GPIO_OffPin(GPIOA, GPIO_PIN_7); 
  HAL_GPIO_OffPin(GPIOA, GPIO_PIN_6); 
  HAL_Delay(delay);

  //Blink 
  HAL_GPIO_OnPin(GPIOA, GPIO_PIN_5); 
  HAL_GPIO_OnPin(GPIOF, GPIO_PIN_0);
  HAL_GPIO_OnPin(GPIOA, GPIO_PIN_7); 
  HAL_GPIO_OnPin(GPIOA, GPIO_PIN_6); 
  HAL_Delay(delay);
  HAL_GPIO_OffPin(GPIOA, GPIO_PIN_5); 
  HAL_GPIO_OffPin(GPIOF, GPIO_PIN_0);
  HAL_GPIO_OffPin(GPIOA, GPIO_PIN_7); 
  HAL_GPIO_OffPin(GPIOA, GPIO_PIN_6); 
  HAL_Delay(delay);
  HAL_GPIO_OnPin(GPIOA, GPIO_PIN_5); 
  HAL_GPIO_OnPin(GPIOF, GPIO_PIN_0);
  HAL_GPIO_OnPin(GPIOA, GPIO_PIN_7); 
  HAL_GPIO_OnPin(GPIOA, GPIO_PIN_6); 
  HAL_Delay(delay); 
  HAL_GPIO_OffPin(GPIOA, GPIO_PIN_5); 
  HAL_GPIO_OffPin(GPIOF, GPIO_PIN_0);
  HAL_GPIO_OffPin(GPIOA, GPIO_PIN_7); 
  HAL_GPIO_OffPin(GPIOA, GPIO_PIN_6); 
  HAL_Delay(delay);
  HAL_GPIO_OnPin(GPIOA, GPIO_PIN_5); 
  HAL_GPIO_OnPin(GPIOF, GPIO_PIN_0);
  HAL_GPIO_OnPin(GPIOA, GPIO_PIN_7); 
  HAL_GPIO_OnPin(GPIOA, GPIO_PIN_6); 
  HAL_Delay(delay);
  HAL_GPIO_OffPin(GPIOA, GPIO_PIN_5); 
  HAL_GPIO_OffPin(GPIOF, GPIO_PIN_0);
  HAL_GPIO_OffPin(GPIOA, GPIO_PIN_7); 
  HAL_GPIO_OffPin(GPIOA, GPIO_PIN_6); 
  HAL_Delay(delay);
}

// Seqeuence 4
void slowrouletteSequence()
{
  HAL_GPIO_OnPin(GPIOF, GPIO_PIN_0); 
  HAL_Delay(delay2);
  HAL_GPIO_OffPin(GPIOF, GPIO_PIN_0); 
  HAL_Delay(delay2);
  HAL_GPIO_OnPin(GPIOA, GPIO_PIN_5);
  HAL_Delay(delay2);
  HAL_GPIO_OffPin(GPIOA, GPIO_PIN_5);
  HAL_Delay(delay2);
  HAL_GPIO_OnPin(GPIOA, GPIO_PIN_6); 
  HAL_Delay(delay2);
  HAL_GPIO_OffPin(GPIOA, GPIO_PIN_6); 
  HAL_Delay(delay2);
  HAL_GPIO_OnPin(GPIOA, GPIO_PIN_7); 
  HAL_Delay(delay2);
  HAL_GPIO_OffPin(GPIOA, GPIO_PIN_7); 
  HAL_Delay(delay2);

  HAL_GPIO_OnPin(GPIOA, GPIO_PIN_7); 
  HAL_Delay(delay2);
  HAL_GPIO_OffPin(GPIOA, GPIO_PIN_7); 
  HAL_Delay(delay2);
  HAL_GPIO_OnPin(GPIOA, GPIO_PIN_6); 
  HAL_Delay(delay2);
  HAL_GPIO_OffPin(GPIOA, GPIO_PIN_6); 
  HAL_Delay(delay2);
  HAL_GPIO_OnPin(GPIOA, GPIO_PIN_5);
  HAL_Delay(delay2);
  HAL_GPIO_OffPin(GPIOA, GPIO_PIN_5);
  HAL_Delay(delay2);
  HAL_GPIO_OnPin(GPIOF, GPIO_PIN_0); 
  HAL_Delay(delay2);
  HAL_GPIO_OffPin(GPIOF, GPIO_PIN_0); 
  HAL_Delay(delay2);
}

// Sequence 5
void allblinkSequence()
{
  HAL_GPIO_OnPin(GPIOA, GPIO_PIN_5); 
  HAL_GPIO_OnPin(GPIOF, GPIO_PIN_0);
  HAL_GPIO_OnPin(GPIOA, GPIO_PIN_7); 
  HAL_GPIO_OnPin(GPIOA, GPIO_PIN_6); 
  HAL_Delay(delay3);
  HAL_GPIO_OffPin(GPIOA, GPIO_PIN_6); 
  HAL_GPIO_OffPin(GPIOA, GPIO_PIN_5);
  HAL_GPIO_OffPin(GPIOF, GPIO_PIN_0); 
  HAL_GPIO_OffPin(GPIOA, GPIO_PIN_7);
  HAL_Delay(delay);

  HAL_GPIO_OnPin(GPIOF, GPIO_PIN_0); 
  HAL_GPIO_OnPin(GPIOA, GPIO_PIN_6);
  HAL_Delay(delay);
  HAL_GPIO_OffPin(GPIOF, GPIO_PIN_0); 
  HAL_GPIO_OffPin(GPIOA, GPIO_PIN_6);
  HAL_Delay(delay);
  HAL_GPIO_OnPin(GPIOA, GPIO_PIN_5); 
  HAL_GPIO_OnPin(GPIOA, GPIO_PIN_7);
  HAL_Delay(delay);
  HAL_GPIO_OffPin(GPIOA, GPIO_PIN_5); 
  HAL_GPIO_OffPin(GPIOA, GPIO_PIN_7);
  HAL_Delay(delay);

  HAL_GPIO_OnPin(GPIOA, GPIO_PIN_5); 
  HAL_Delay(delay);
  HAL_GPIO_OffPin(GPIOA, GPIO_PIN_5);
  HAL_Delay(delay);
  HAL_GPIO_OnPin(GPIOA, GPIO_PIN_7);
  HAL_Delay(delay);
  HAL_GPIO_OffPin(GPIOA, GPIO_PIN_7);
  HAL_Delay(delay); 
  HAL_GPIO_OnPin(GPIOA, GPIO_PIN_6);
  HAL_Delay(delay);
  HAL_GPIO_OffPin(GPIOA, GPIO_PIN_6);
  HAL_Delay(delay);
  HAL_GPIO_OnPin(GPIOF, GPIO_PIN_0);
  HAL_Delay(delay);
  HAL_GPIO_OffPin(GPIOF, GPIO_PIN_0);
  HAL_Delay(delay);
}

// Sequence 6
void fastrouletteSequence()
{
  HAL_GPIO_OnPin(GPIOF, GPIO_PIN_0); 
  HAL_Delay(delay4);
  HAL_GPIO_OffPin(GPIOF, GPIO_PIN_0);
  HAL_Delay(delay4);
  HAL_GPIO_OnPin(GPIOA, GPIO_PIN_5); 
  HAL_Delay(delay4);
  HAL_GPIO_OffPin(GPIOA, GPIO_PIN_5);
  HAL_Delay(delay4);
  HAL_GPIO_OnPin(GPIOA, GPIO_PIN_6); 
  HAL_Delay(delay4);
  HAL_GPIO_OffPin(GPIOA, GPIO_PIN_6);
  HAL_Delay(delay4);
  HAL_GPIO_OnPin(GPIOA, GPIO_PIN_7); 
  HAL_Delay(delay4);
  HAL_GPIO_OffPin(GPIOA, GPIO_PIN_7);
  HAL_Delay(delay4);

  HAL_GPIO_OnPin(GPIOF, GPIO_PIN_0); 
  HAL_Delay(delay4);
  HAL_GPIO_OffPin(GPIOF, GPIO_PIN_0);
  HAL_Delay(delay4);
  HAL_GPIO_OnPin(GPIOA, GPIO_PIN_5); 
  HAL_Delay(delay4);
  HAL_GPIO_OffPin(GPIOA, GPIO_PIN_5);
  HAL_Delay(delay4);
  HAL_GPIO_OnPin(GPIOA, GPIO_PIN_6); 
  HAL_Delay(delay4);
  HAL_GPIO_OffPin(GPIOA, GPIO_PIN_6);
  HAL_Delay(delay4);
  HAL_GPIO_OnPin(GPIOA, GPIO_PIN_7); 
  HAL_Delay(delay4);
  HAL_GPIO_OffPin(GPIOA, GPIO_PIN_7);
  HAL_Delay(delay4);

  HAL_GPIO_OnPin(GPIOF, GPIO_PIN_0); 
  HAL_Delay(delay4);
  HAL_GPIO_OffPin(GPIOF, GPIO_PIN_0);
  HAL_Delay(delay4);
  HAL_GPIO_OnPin(GPIOA, GPIO_PIN_5); 
  HAL_Delay(delay4);
  HAL_GPIO_OffPin(GPIOA, GPIO_PIN_5);
  HAL_Delay(delay4);
  HAL_GPIO_OnPin(GPIOA, GPIO_PIN_6); 
  HAL_Delay(delay4);
  HAL_GPIO_OffPin(GPIOA, GPIO_PIN_6);
  HAL_Delay(delay4);
  HAL_GPIO_OnPin(GPIOA, GPIO_PIN_7); 
  HAL_Delay(delay4);
  HAL_GPIO_OffPin(GPIOA, GPIO_PIN_7);
  HAL_Delay(delay4);

  HAL_GPIO_OnPin(GPIOF, GPIO_PIN_0); 
  HAL_Delay(delay4);
  HAL_GPIO_OffPin(GPIOF, GPIO_PIN_0);
  HAL_Delay(delay4);
  HAL_GPIO_OnPin(GPIOA, GPIO_PIN_5); 
  HAL_Delay(delay4);
  HAL_GPIO_OffPin(GPIOA, GPIO_PIN_5);
  HAL_Delay(delay4);
  HAL_GPIO_OnPin(GPIOA, GPIO_PIN_6); 
  HAL_Delay(delay4);
  HAL_GPIO_OffPin(GPIOA, GPIO_PIN_6);
  HAL_Delay(delay4);
  HAL_GPIO_OnPin(GPIOA, GPIO_PIN_7); 
  HAL_Delay(delay4);
  HAL_GPIO_OffPin(GPIOA, GPIO_PIN_7);
  HAL_Delay(delay4);

  HAL_GPIO_OnPin(GPIOF, GPIO_PIN_0); 
  HAL_Delay(delay4);
  HAL_GPIO_OffPin(GPIOF, GPIO_PIN_0);
  HAL_Delay(delay4);
  HAL_GPIO_OnPin(GPIOA, GPIO_PIN_5); 
  HAL_Delay(delay4);
  HAL_GPIO_OffPin(GPIOA, GPIO_PIN_5);
  HAL_Delay(delay4);
  HAL_GPIO_OnPin(GPIOA, GPIO_PIN_6); 
  HAL_Delay(delay4);
  HAL_GPIO_OffPin(GPIOA, GPIO_PIN_6);
  HAL_Delay(delay4);
  HAL_GPIO_OnPin(GPIOA, GPIO_PIN_7); 
  HAL_Delay(delay4);
  HAL_GPIO_OffPin(GPIOA, GPIO_PIN_7);
  HAL_Delay(delay4);

  HAL_GPIO_OnPin(GPIOF, GPIO_PIN_0); 
  HAL_Delay(delay4);
  HAL_GPIO_OffPin(GPIOF, GPIO_PIN_0);
  HAL_Delay(delay4);
  HAL_GPIO_OnPin(GPIOA, GPIO_PIN_5); 
  HAL_Delay(delay4);
  HAL_GPIO_OffPin(GPIOA, GPIO_PIN_5);
  HAL_Delay(delay4);
  HAL_GPIO_OnPin(GPIOA, GPIO_PIN_6); 
  HAL_Delay(delay4);
  HAL_GPIO_OffPin(GPIOA, GPIO_PIN_6);
  HAL_Delay(delay4);
  HAL_GPIO_OnPin(GPIOA, GPIO_PIN_7); 
  HAL_Delay(delay4);
  HAL_GPIO_OffPin(GPIOA, GPIO_PIN_7);
  HAL_Delay(delay4);

  HAL_GPIO_OnPin(GPIOF, GPIO_PIN_0); 
  HAL_Delay(delay4);
  HAL_GPIO_OffPin(GPIOF, GPIO_PIN_0);
  HAL_Delay(delay4);
  HAL_GPIO_OnPin(GPIOA, GPIO_PIN_5); 
  HAL_Delay(delay4);
  HAL_GPIO_OffPin(GPIOA, GPIO_PIN_5);
  HAL_Delay(delay4);
  HAL_GPIO_OnPin(GPIOA, GPIO_PIN_6); 
  HAL_Delay(delay4);
  HAL_GPIO_OffPin(GPIOA, GPIO_PIN_6);
  HAL_Delay(delay4);
  HAL_GPIO_OnPin(GPIOA, GPIO_PIN_7); 
  HAL_Delay(delay4);
  HAL_GPIO_OffPin(GPIOA, GPIO_PIN_7);
  HAL_Delay(delay4);

  HAL_GPIO_OnPin(GPIOF, GPIO_PIN_0); 
  HAL_Delay(delay4);
  HAL_GPIO_OffPin(GPIOF, GPIO_PIN_0);
  HAL_Delay(delay4);
  HAL_GPIO_OnPin(GPIOA, GPIO_PIN_5); 
  HAL_Delay(delay4);
  HAL_GPIO_OffPin(GPIOA, GPIO_PIN_5);
  HAL_Delay(delay4);
  HAL_GPIO_OnPin(GPIOA, GPIO_PIN_6); 
  HAL_Delay(delay4);
  HAL_GPIO_OffPin(GPIOA, GPIO_PIN_6);
  HAL_Delay(delay4);
  HAL_GPIO_OnPin(GPIOA, GPIO_PIN_7); 
  HAL_Delay(delay4);
  HAL_GPIO_OffPin(GPIOA, GPIO_PIN_7);
  HAL_Delay(delay4);
}

// Sequence 7
void sequences(int sequence)
{
  switch (sequence)
  {
  case 1:
    allSequence();
    break;
  case 2:
    earsSequence();
    break;
  case 3:
    rouletteSequence();
    break;
  case 4:
    slowrouletteSequence();
    break;
  case 5:
    allblinkSequence();
    break;
  case 6:
    fastrouletteSequence();
    break;
  default:
    ledsOn();
    HAL_Delay(1000);
    break;
  }
}

int main(void)
{
  HAL_Init();

  APP_LedConfig();

  BSP_USART_Config();

  allonSequence();
  
  unlockSequence();

  alloffSequence();

  while (1)
  {
    for (uint8_t c = 1; c < 7; c++)
    {
      sequences(c);
    }
  }
}

static void APP_LedConfig(void)
{
  GPIO_InitTypeDef GPIO_InitStruct;

  __HAL_RCC_GPIOA_CLK_ENABLE();

  GPIO_InitStruct.Pin = GPIO_PIN_1;
  GPIO_InitStruct.Mode = GPIO_MODE_OUTPUT_PP;
  GPIO_InitStruct.Pull = GPIO_PULLUP;
  GPIO_InitStruct.Speed = GPIO_SPEED_FREQ_HIGH;
  HAL_GPIO_Init(GPIOA, &GPIO_InitStruct);

  __HAL_RCC_GPIOA_CLK_ENABLE();

  GPIO_InitStruct.Pin = GPIO_PIN_6;
  GPIO_InitStruct.Mode = GPIO_MODE_OUTPUT_PP;
  GPIO_InitStruct.Pull = GPIO_PULLUP;
  GPIO_InitStruct.Speed = GPIO_SPEED_FREQ_HIGH;
  HAL_GPIO_Init(GPIOA, &GPIO_InitStruct);

  __HAL_RCC_GPIOA_CLK_ENABLE();

  GPIO_InitStruct.Pin = GPIO_PIN_7;
  GPIO_InitStruct.Mode = GPIO_MODE_OUTPUT_PP;
  GPIO_InitStruct.Pull = GPIO_PULLUP;
  GPIO_InitStruct.Speed = GPIO_SPEED_FREQ_HIGH;

  HAL_GPIO_Init(GPIOA, &GPIO_InitStruct);

  __HAL_RCC_GPIOA_CLK_ENABLE();

  GPIO_InitStruct.Pin = GPIO_PIN_5;
  GPIO_InitStruct.Mode = GPIO_MODE_OUTPUT_PP;
  GPIO_InitStruct.Pull = GPIO_PULLUP;
  GPIO_InitStruct.Speed = GPIO_SPEED_FREQ_HIGH;

  HAL_GPIO_Init(GPIOA, &GPIO_InitStruct);

  __HAL_RCC_GPIOF_CLK_ENABLE();

  GPIO_InitStruct.Pin = GPIO_PIN_0;
  GPIO_InitStruct.Mode = GPIO_MODE_OUTPUT_PP;
  GPIO_InitStruct.Pull = GPIO_PULLUP;
  GPIO_InitStruct.Speed = GPIO_SPEED_FREQ_HIGH;

  HAL_GPIO_Init(GPIOF, &GPIO_InitStruct);
}

void APP_ErrorHandler(void)
{
  while (1)
    ;
}

#ifdef USE_FULL_ASSERT

void assert_failed(uint8_t *file, uint32_t line)
{
  while (1)
  {
  }
}
#endif /* USE_FULL_ASSERT */

/************************ (C) COPYRIGHT Puya *****END OF FILE******************/

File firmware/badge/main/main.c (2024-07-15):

#include <stdio.h>
#include "ajo_module.h"
#include "cat_console.h"
#include "catdos_module.h"
#include "esp_event.h"
#include "esp_log.h"
#include "esp_timer.h"
#include "keyboard_module.h"
#include "menu_screens_modules.h"
#include "neopixels_module.h"
#include "open_thread.h"
#include "preferences.h"

static const char* TAG = "main";

void reboot_counter() {
  int32_t counter = preferences_get_int("reboot_counter", 0);
  ESP_LOGI(TAG, "Reboot counter: %ld", counter);
  counter++;
  preferences_put_int("reboot_counter", counter);
}

void app_main(void) {
  // ESP_ERROR_CHECK(esp_event_loop_create_default());
  neopixels_module_begin();

  neopixels_set_pixels(4, 30, 0, 30);
  neopixels_refresh();

  preferences_begin();
  menu_screens_begin();
  keyboard_module_begin();
  reboot_counter();

  ajo_module_init();
  // cat_console_begin();

  bool is_ajo = ajo_module_get_state();
  ESP_LOGI(TAG, "AJO Module State: %d", is_ajo);

  neopixels_set_pixels(4, 0, 0, 0);
  neopixels_refresh();
}

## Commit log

2024-04-23 feat(Hw):Added_LED´s_Buttons
    [badge-bsides-cdmx-2024.kicad_sch]
2024-04-29 feat(hw): add labels schematic
    [badge-bsides-cdmx-2024.kicad_sch]
2024-05-20 feat(Hw): Shitty Addon PCB added
    [Bsides_2024_Guest.kicad_pcb, Bsides_2024_Guest.kicad_sch, Bsides_2024_ShittyAddon.kicad_pcb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]
2024-05-22 feat(Hw): Start new floorplan
    [Bsides_2024_Community.kicad_pcb, Bsides_2024_Community.kicad_sch, Bsides_2024_Guest.kicad_pcb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]
2024-05-27 feat(Hw): Update PCB
    [Bsides_2024_Community.kicad_pcb, Bsides_2024_Community.kicad_sch, Bsides_2024_Guest.kicad_pcb]
2024-06-04 feat(Hw): Update PCB and schematic
    [Bsides_2024_Community.kicad_pcb, Bsides_2024_Community.kicad_sch, Bsides_2024_Guest.kicad_pcb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]
2024-06-10 feat: add minino firmware
    [partitions.csv]
2024-06-11 Revert "Merge branch 'main' of https://github.com/ElectronicCats/badge-bsides-cdmx-2024"
    This reverts commit 844f9cf1141b02d246949023f3a5d84c3d1d6870, reversing
    changes made to df45190e2e7c4c17babbd6f5b24a18277498f0c6.
    [Bsides_2024_Community.kicad_pcb, Bsides_2024_Community.kicad_sch, Bsides_2024_Guest.kicad_pcb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]
2024-06-11 feat(Hw): Update schematics
    [Bsides_2024_Community.kicad_sch, Bsides_2024_Guest.kicad_sch, Bsides_2024_ShittyAddon.kicad_pcb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]
2024-06-11 feat(Hw): Update route
    [Bsides_2024_Community.kicad_sch, Bsides_2024_Guest.kicad_pcb, Bsides_2024_Guest.kicad_sch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]
2024-06-12 Update route and schematic
    [Bsides_2024_Community.kicad_pcb, Bsides_2024_Community.kicad_sch, Bsides_2024_Guest.kicad_pcb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]
2024-06-12 fet(Hw): Update route
    [Bsides_2024_Sponsor.kicad_pcb, Bsides_2024_Staff.kicad_pcb]
2024-06-13 feat(Hw): Update BOM ShittyAddon
    [Bsides_2024_ShittyAddon.kicad_sch]
2024-06-13 Faet(Hw): Update BOM Speaker
    [Bsides_2024_Speaker.kicad_sch]
2024-06-13 feat(Hw): Update BOM
    [Bsides_2024_Community.kicad_sch, Bsides_2024_Speaker.kicad_pcb, Bsides_2024_Sponsor.kicad_sch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]
2024-06-13 feat(Hw): Update route Speaker and Sponsor
    [Bsides_2024_Speaker.kicad_pcb, Bsides_2024_Sponsor.kicad_pcb]
2024-06-14 feat(Hw): Update route Community
    [Bsides_2024_Community.kicad_pcb, Bsides_2024_Community.kicad_sch]
2024-06-14 feat(Hw): Labels added
    [Bsides_2024_Community.kicad_pcb, Bsides_2024_Guest.kicad_pcb, Bsides_2024_Speaker.kicad_pcb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]
2024-06-14 feat(Hw): Update labels
    [Bsides_2024_Guest.kicad_pcb, Bsides_2024_Speaker.kicad_pcb, Bsides_2024_Sponsor.kicad_pcb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]
2024-06-14 feat(Hw): Update schematic and route
    [Bsides_2024_Staff.kicad_pcb, Bsides_2024_Staff.kicad_sch]
2024-06-14 feat(Hw): Update .step
    [Bsides_2024_Sponsor.kicad_pcb, Bsides_2024_Staff.kicad_pcb]
2024-06-14 feat(Hw): Move labels
    [Bsides_2024_Sponsor.kicad_pcb]
2024-06-14 feat(hw): add labels and logos speaker
    [Bsides_2024_Speaker.kicad_pcb]
2024-06-14 feat(hw): add logos staff
    [Bsides_2024_Staff.kicad_pcb]
2024-06-14 feat(hw): logos sponsor
    [Bsides_2024_Sponsor.kicad_pcb]
2024-06-14 feat(hw): add logos guest
    [Bsides_2024_Guest.kicad_pcb]
2024-06-14 feat(hw): add logos community
    [Bsides_2024_Community.kicad_pcb]
2024-06-14 feat(hw): add labels
    [Bsides_2024_Community.kicad_pcb]
2024-06-14 feat(hw): add logos shitty addon
    [Bsides_2024_ShittyAddon.kicad_pcb]
2024-06-14 feat(Hw): Update label ShittyAddon
    [Bsides_2024_ShittyAddon.kicad_pcb]
2024-06-18 refactor: zigbee toggle button & ble spam & wifi deauth bitmaps resized
2024-06-19 feat: Implement send uart packet
    - Send UART packet
    - Change Zigbee module
    - Add loop menu options
    Note: Bad FCS, requires check the calculation function
2024-06-19 feat: Ajolote animation
    - Fix init logo
    [ajo_module.c]
2024-06-24 fix: badge connect failed to start
    [lobby_manager.c]
2024-06-25 fix: game exit bug
    [lobby_manager.c]
2024-07-01 fix: avoid leds on software reset
    [main.c]
2024-07-01 fix: free memory in menu screens modules
    [main.c]
2024-07-01 feat: add promiscuous functions to open thread
2024-07-01 feat: add open thread broadcast app
    [partitions.csv]
2024-07-02 feat: order players strenght
    [partitions.csv]
2024-07-02 fix: games module exit
    [lobby_manager.c]
2024-07-04 feat: Remove led_function
2024-07-06 feat: add rssi filter
2024-07-08 feat: arm wretstling game
2024-07-09 feat: arm wrestling game update
2024-07-10 refactor: thread broadcast screen
2024-07-10 refactor: replace uart to jtag config for esp console
    [cat_console.c]
2024-07-11 feat: Ajolotin & LEDS
2024-07-11 feat: added arm game data function
2024-07-12 refactor: zb switch labels
2024-07-12 feat: using neopixels in arm game
2024-07-12 refactor: leds replaced by neopixels
    [main.c]
